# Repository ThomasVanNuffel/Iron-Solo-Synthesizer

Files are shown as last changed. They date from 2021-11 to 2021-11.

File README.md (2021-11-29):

# Main Directory
This repository is about the two phases of the project.

First phase: Practise Enterprise 1

    - XC888-DIL (microcontroller)
    - Input matrix with keys from keyboard
    - Led matrix
    - Serial interface with signal generators (with chip selector)

Second phase: Practise Enterprise 2

    - STM32F7508-DK (microcontroller)
    - Better serial interface with more signal generators
    - Communication with XC888 (to have all features of previous year)
    - MIDI communication
    - Hardware audio effects:
        - Envelopes
        - Low pass filter
        - High pas filter

    - Line input with small mixing stage

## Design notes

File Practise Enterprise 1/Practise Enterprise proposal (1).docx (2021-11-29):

# Practise Enterprise proposal

Thomas Van Nuffel

# Description

I want to make a synthesizer based on the XC888 which is compatible with MIDI. The synthesizer is a standalone, which only needs power to work. I will make an output stage with different kinds of jacks to connect to speakers etc. Also, a headphone connection will be applied.

## MIDI interface

This is not part of my project. I just want to make a synthesizer compatible with MIDI. But I do not make a full MIDI interface. Because of the simple reason, you have guys who build keyboards and guys who make MIDI interfaces. I make a keyboard compatible with MIDI, but I do not reinvent the MIDI. It exists and I use it. In my block diagram I added the MIDI interface but that is just because my keyboard works with MIDI I/O.

# Features

### General

I make a complete synthesizer. So, you can play a synthesizer. But my purpose is to make it simple for the user. So, with different modes the user can personalize for his own purpose.

The general features are:

- Synthesizer that is compatible with MIDI (to connect to pc or other devices)
- Making sound due incoming MIDI signals
- Output to speakers/ headphones
- Input going through an amplifier to the output.
- Leds are indicating which notes are on at the time.

### Modes

- Synth mode
  - All functions will work
  - MIDI still can be applied.
- MIDI mode
  - Every hardware for sound will be disabled (less power consumption)
- Adapter
  - In Synth mode: a power supply needs to be applied.
  - In MIDI mode: power supply or power from USB to PC

### Synth features

- Three basic output waveforms
  - Sinewave
  - Square wave
  - Triangle wave
- Effects
  - Envelope
    - This is a voltage controlled system with an attack and release
  - Low pass filter
  - High pass filter
- Output stage
  - Master
    - XLR
    - RCA
    - Jack
  - Headphone
- Mode to decide in which DDS the next sound will be generated.
  - One after the other, left to right, after that begin left.
  - Search for the first one which is not playing right now.

# Hardware I/O

## Input

- Maximal 96 keys

Sum is at absolute maximum 128

- Maximal 32 knobs
- Sliders (10)
- AUX in

## Output

- Audio master output (speakers)
  - RCA
  - XLR
  - Jack
- Headphone output
  - Jack
- Leds indicating which notes are pressed at the moment (midi or knobs)

## Other

- MIDI interface
- Power supply
  - Wall outlet
  - USB

# How it’s gonna work

You plug it in the wall outlet. The controller has an on/Off knob. Turn it on. Choose MIDI mode or Synth mode. A synthesizer speaks for itself how to use it. It has built-in speakers, so you do not need external speakers. Connect to a MIDI interface to use as a MIDI keyboard. You can play notes, you can use sliders. Dipswitches are indicating which region of the keyboard is enabled for controlling by knobs, the other parts are MIDI only. This will result in an interactive learn function.

# Extra features (if there is time left)

I am thinking of making some extra features with:

- Add more input
- Add more effects
- Optimize my synths compatibility with any DAW on my computer by MIDI. For example, that slider is assigned to this effect in any software.
- Give the leds on top of the keys another color (daresay one color for all the leds)
- Improving the “Learn to play” function.

# Photos

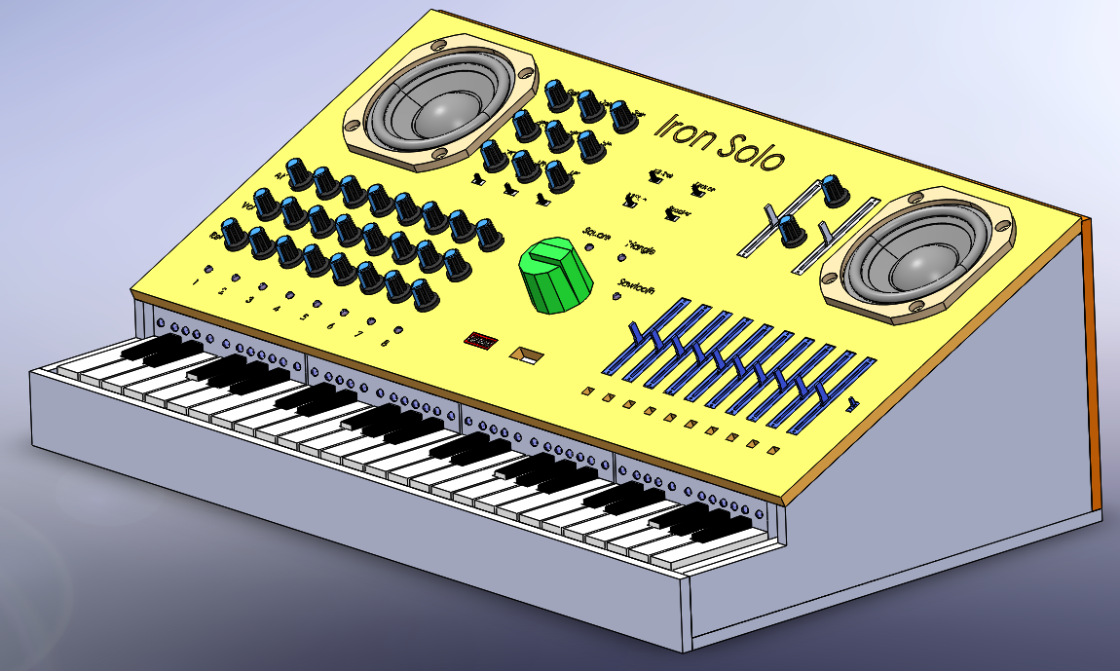
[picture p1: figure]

Master section

LPF and HPF

8 DDS modules with envelope and volume

MIDI sliders

Waveform selector

49 leds

Region selector

49 keys

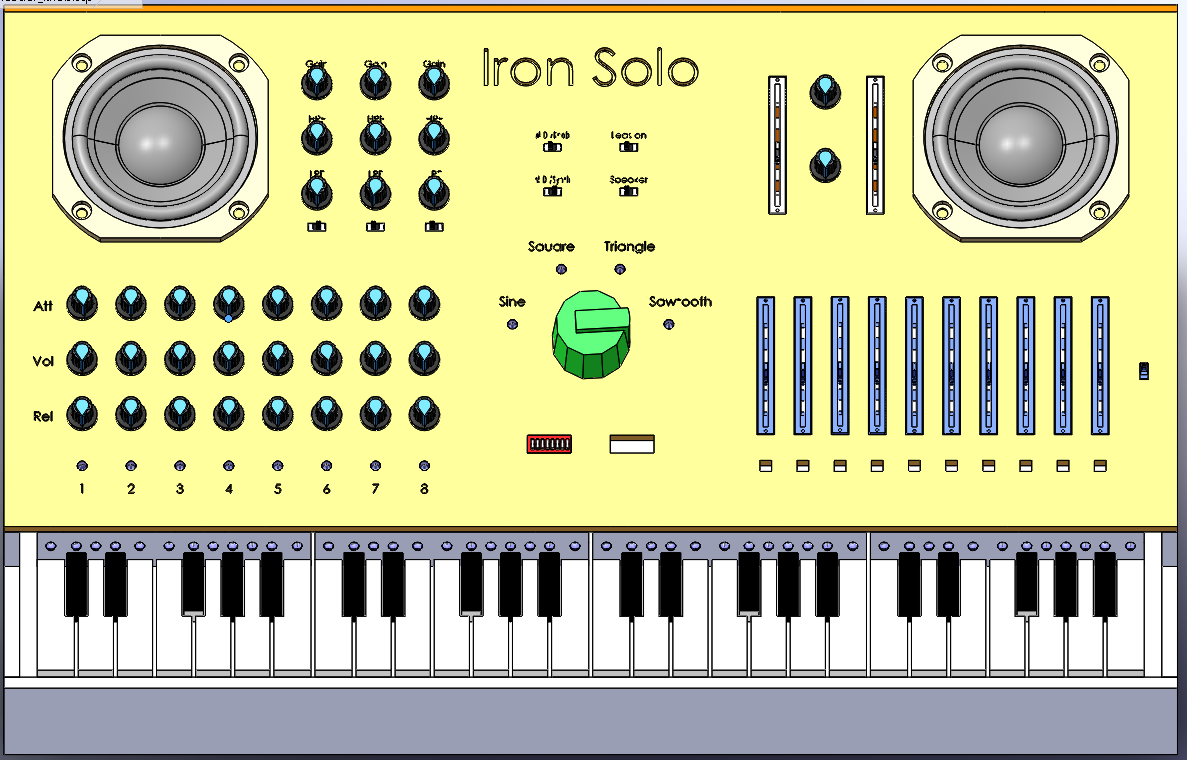
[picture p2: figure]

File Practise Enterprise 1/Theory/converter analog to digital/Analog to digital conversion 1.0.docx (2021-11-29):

# Analog to digital conversion

# Intro:

An analog signal is a signal that is continuously in time and in amplitude. The resolution is by definition infinitely. When an analog signal is made digital does this mean that we need to discretize the signal. A discrete digital signal is the counterpart of a continuous signal. To make it digital we need to take a moment and save it. Then take the next moment and save it again. This happens at a certain frequency. That frequency is called the sampling frequentie. Every moment there will be a sample of the sound, and many sounds after each other will result in a more or less smooth signal. The higher this sample frequency, the higher the resolution of the sound.

# Working

The analog signal is coming into the AD-converter and will be edited by a low pass filter. This is done for preventing aliasing. This occurs when the sample frequentie isn’t at least two times higher then the highest frequentie. If the sound frequency is too high in relation to the sample frequency, you get audio with horrible sound in the high frequencies. So our sample frequency must be high enough to pass high frequency sound (20kHz). So we need to sample at least 40.000Hz, or the standard sampling frequency of 44.100Hz. After this low pass filter the ADC takes samples at the sample frequency. This means that we are going to look at the exact amplitude of the sound wave. Well known systems are the voice telephony with a sample rate of 8kHz. So the maximal frequency we can sample is 4kHz (due the aliasing low pass filter). Every sample, every amplitude is a number that contains bits. The amount of bits determines how exactly the signal is measured. And that’s logical. Because if you have to divide a signal over 8 bits. Or you have to divide that same signal over 32 bits. The precision of the 32 bits is four times better then the 8 bits. When the analog signal is filtered and quantized. The analog signal has become digital.

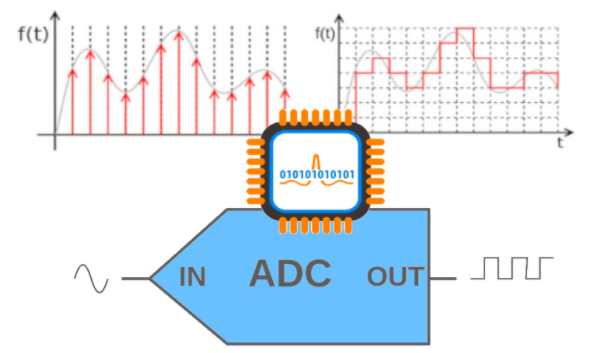
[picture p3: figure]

## Summary

- The analog input is quantized in digital amplitudes.
- The more refined the quantization. The higher the amount of bits needed.
- The bigger the amount of bits per amplitude the exacter the signal.
- The bigger the sample frequency, the bigger is the highest frequency without aliasing

## The implementation

Sampling uses a “sample-and-hold circuit”. At fixed time a sample is made from the analog signal. You can see it as a switch that turns on and off at fixed times. And a capacitor is used for holding the “memory” of that one amplitude.

That amplitude is compared to fixed levels. Here is a rounding error. This is the quantisation noise. The network to do this is a series circuit of four resistors where a reference voltage is applied to. After the first resistor you have 25% of the voltage. After the second one you have 50%, after the third 75% and after the fourth 100% of the voltage. These levels are together with the sample connected to a differential amplifier.

- If the sample amplitude is bigger then 25%, the output of the first differential amplifier changes polarity
- If the sample amplitude is bigger then 50%, the output of the second differential amplifier changes polarity
- If the sample amplitude is bigger then 75%, the output of the third differential amplifier changes polarity
- If the sample amplitude is bigger then 100%, the output of the fourth differential amplifier changes polarity

And last but not least you have a logic circuit which is granting binary numbers to the signal.

- Level 1 is 00(2)
- Level 2 is 01(2)
- Level 3 is 10(2)
- Level 4 is 11(2)

## Improve the quality

- Increase the amount of samples per second
- Increase the amount of bits per sample
- Faster sample-and-hold circuit
- More extensive networks
- Every bit extra is a doubling of the amount of resistors needed
- The tolerance on the resistors must be as low as possible

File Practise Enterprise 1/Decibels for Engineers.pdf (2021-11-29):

Decibels for engineers.

While dB is a very handy way of expressing large numbers, like we often have to deal with in amplifier circuits, unfortunately a lot of engineers fail the ability to juggle with them. So apart from the “official” mathematical way of dealing with dB’s, we will now learn a handy way how to use them by only remembering 3 numbers.

Decibel is a number that describes how the ratio is between two voltages or two powers

Voltage dB = 20 * LOG (A1 / A2)

Power dB = 10 * LOG (P1 / P2)

As we do not always have a scientific calculator at hand there is is truck that helps you handle these memorizing only 3 numbers:

POWER deciBels (small d capital B)

times two = + 3 dB

divided by two = - 3 dB

times four = + 6 dB

divided by four = - 6 dB

times ten = + 10 dB

divided by ten = - 10 dB

other values can be derived from this, like FIVE = TEN divided by TWO = +10 dB – 3 dB = 5 dB

times hundred = TEN times TEN = +10 dB + 10 dB = 20 dB

VOLTAGE deciBels

times two = + 6 dB

divided by two = - 6 dB

times four = + 12 dB

divided by four = - 12 dB

times ten = + 20 dB

divided by ten = - 20 dB

## An overview:

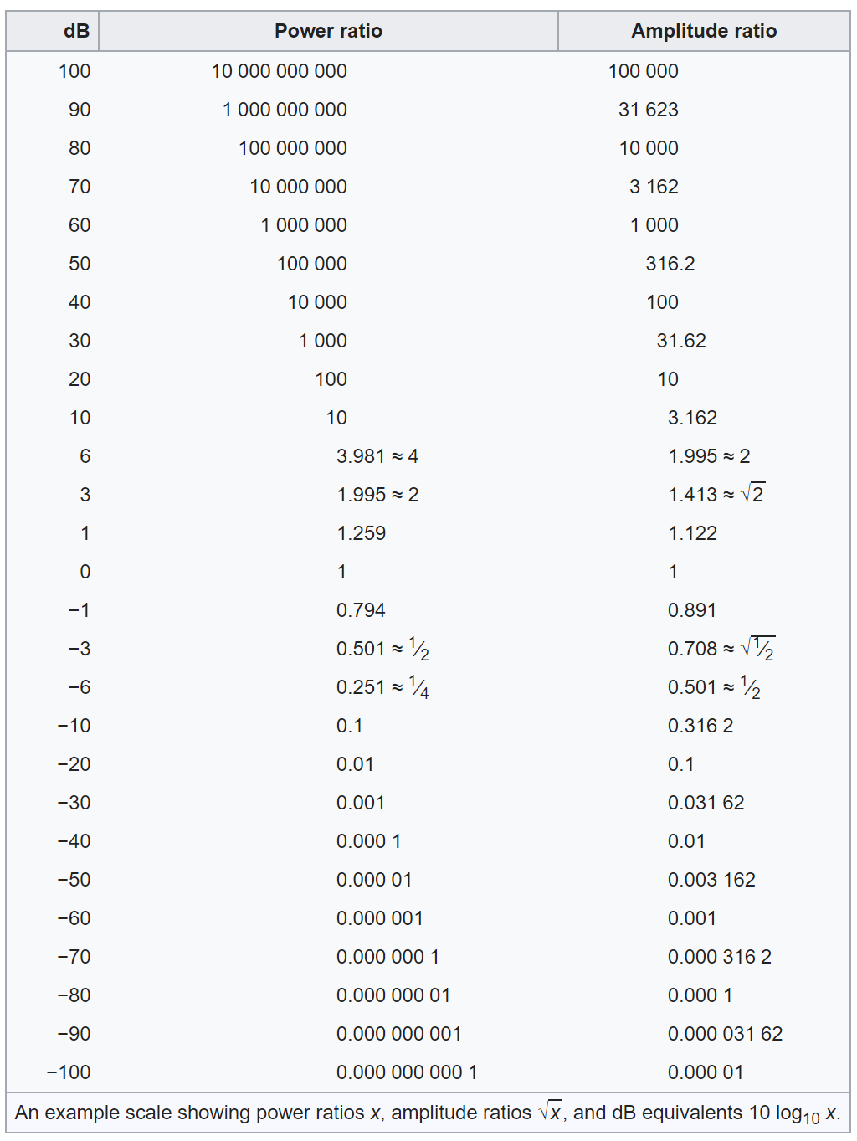
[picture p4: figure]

(source https://en.wikipedia.org/wiki/Decibel )

## Exercices:

An antenna is driven by a transmitter power of 1000 Watts. How much is this in dBm ? (dBm is the power output compared to 1 mW)

A microphone amplifier has a voltage gain of 100, How many dB’s gain has it ?

The noise floor of a PA system is 1.000.000 below the nominal output power. How much is the signal to noise ratio ?

A system consists of 3 cascaded amplifiers, the first one having 1000 times voltage amplification, the second 500 and the last stage 40. How much is the total gain in dB.

A 100 Watts transmitter is feeding a 6 dB gain antenna using a cable that has 3 dB loss. How much is the effectively radiated power in dBm ?

A satellite van has a dish antenna with 60 dB gain and is driven by a travelling wave tube amplifier that has a maximum output power of 500W via a waveguide that has 3 dB loss. How much is the effectively radiated power in dBW ?

The signal at the output of a low noise microphone amplifier is 1 Vpp. The signal to noise ratio is 80 dB. How much is the noise level at the output and how much is the microphone signal at the input when the amplifier has a 1000 times voltage gain ?

The maximum input power of an amplifier is 0 dBm while the uncompressed gain is 40 dB. How much Watts will the amplifier deliver to the load ?

A cabling system at a cellphone tower consists of a patch cable of 0,3 dB loss, followed by a feed line that has 1,5 dB loss, an antenna splitter that has 3 dB loss and an antenna feed patch line that adds another 0,2 dB of loss.. When the transmitter delivers a power output of 20 dBW, how much power will my Bird Wattmeter indicate at the antenna terminal (in Watts) ?

An active speaker clips at 10V output level over a 4 ohms speaker resistance at an input voltage of 250 mV. How much is the system gain ?

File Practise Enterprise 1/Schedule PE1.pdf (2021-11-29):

Project Start: 12/10/2020 | Week:1
| | | | 12 | 13
Task | Start | Progress | End | ma | di
Urenregistratie!A1 | Total: | 14 okt 20 | 74% | 30 mei 21
Preparations | 18 okt 20 | 100% | 20 okt 20 | X
https://www.youtube.com/watch?v=un8j6QqpYa0&t=646s Knowing how this works | 18 okt 20 | 100% | 19 okt 20 | X
Getting a Gantt Chart | 19 okt 20 | 100% | 20 okt 20 | X
..\Theory Theory | 18 okt 20 | 100% | 22 jan 21 | X
..\Theory\XC888 Datasheet XC888 | 27 okt 20 | 100% | 15 dec 20 | X
Sensor Research | 19 okt 20 | 100% | 01 dec 20 | X
Scan matrix keys + leds | 14 nov 20 | 100% | 18 nov 20 | X
MIDI | 18 okt 20 | 100% | 29 dec 20 | X
MIDI coding | 28 dec 20 | 100% | 29 dec 20 | X
Analog voltages due PWM | 28 dec 20 | 100% | 29 dec 20 | X
AD9833 | 16 jan 21 | 100% | 22 jan 21 | X
Decibels | 19 dec 20 | 100% | 11 jan 21 | X
Documentation | 14 okt 20 | 73% | 11 apr 21
..\Theory\MIDI MIDI documentation | 14 okt 20 | 100% | 03 nov 20 | X
Scan Matrices | 02 apr 21 | 70% | 11 apr 21
Sound | 17 nov 20 | 100% | 18 nov 20 | X
Hearing | 18 nov 20 | 100% | 18 nov 20 | X
Effects | 01 apr 21 | 70% | 11 apr 21
Envelope | 23 nov 20 | 100% | 12 jan 21 | X
Attenuator | 02 jan 21 | 100% | 07 jan 21 | X
Programming | 14 mrt 21 | 20%
3D design keyboard | | 0%
Schematics | 16 nov 20 | 85% | 11 apr 21
Scan Matrix keys | 16 nov 20 | 100% | 16 nov 20 | X
Master section | 12 dec 20 | 100% | 27 dec 20 | X
Attenuator | 03 jan 21 | 100% | 07 jan 21 | X
Envelope | 03 jan 21 | 100% | 11 jan 21 | X
Envelope2.0 | 28 jan 21 | 100% | 01 feb 21 | X

LPF | 09 jan 21 | 100% | 31 jan 21 | X
HPF | 09 jan 21 | 100% | 31 jan 21 | X
Scan matrix keys | 30 jan 21 | 100% | 30 jan 21 | X
Scan Matrix Leds | 14 mrt 21 | 100% | 11 apr 21 | X
Routings of XC888 | 12 jan 21 | 100% | 25 feb 21
Master section 2.0 | | 0%
Line input amplifier | | 0%
Block diagram | 21 jan 21 | 100% | 10 feb 21 | X
3D design keyboard | 07 feb 21 | 92% | 15 feb 21
Main plate | 07 feb 21 | 95%
Connections input/output audio | 08 feb 21 | 80% | 13 feb 21
Keys implemented | 09 feb 21 | 100% | 15 feb 21 | X
Components | 25 jan 21 | 100% | 19 mrt 21 | X
Speakers | 18 feb 21 | 100% | 08 mrt 21 | X
AD9833 | 25 jan 21 | 100% | 19 mrt 21 | X
Connectors | 25 jan 21 | 100% | 08 mrt 21 | X
XLR | 18 feb 21 | 100% | 08 mrt 21 | X
Jacks | 18 feb 21 | 100% | 08 mrt 21 | X
MIDI | 18 feb 21 | 100% | 08 mrt 21 | X
Log potmeters | 18 feb 21 | 100% | 08 mrt 21 | X
Capacitors | 04 mrt 21 | 100% | 04 mrt 21 | X
Resistors | 04 mrt 21 | 100% | 04 mrt 21 | X
PCB's | 01 feb 21 | 100% | 15 feb 21
Coding | 21 jan 21 | 61% | 25 apr 21
Initialisation | | 97%
SPI interface | 13 mrt 21 | 100% | 15 mrt 21 | X
UART interface | 21 jan 21 | 100% | 24 jan 21 | X
Reset values | | 90%
UART interface | 26 jan 21 | 36% | 11 apr 21
Transmitting | 26 jan 21 | 73% | 26 jan 21
Note on | 26 jan 21 | 100% | 26 jan 21 | X
Note off | 26 jan 21 | 100% | 26 jan 21 | X
Control change | 15 mrt 21 | 90% | 15 mrt 21
Program change | 05 apr 21 | 0% | 11 apr 21

Receiving | 05 apr 21 | 0% | 11 apr 21
Note on | 05 apr 21 | 0% | 11 apr 21
Note off | 05 apr 21 | 0% | 11 apr 21
Communication AD9833 | | 70%
SPI interface | 14 mrt 21 | 90% | 11 apr 21
Coding frequencies | 16 mrt 21 | 50% | 25 apr 21
Scan matrices | | 95%
Reading knobs | 24 jan 21 | 90% | 11 apr 21
Writing leds | 24 jan 21 | 100% | 25 jan 21 | X
Register assigning | 05 feb 21 | 70%
All notes done | | 0%
Assembly | 18 mrt 21 | 26% | 18 apr 21
Soldering Envelopes | 27 mrt 21 | 33% | 27 mrt 21
Soldering Effect | 28 mrt 21 | 70% | 11 apr 21 | X
Soldering protoboards | 05 apr 21 | 0% | 11 apr 21
Soldering Attenuators | 18 mrt 21 | 25% | 11 apr 21
Assembly wooden case | 12 apr 21 | 0% | 18 apr 21
Implement keys | 12 apr 21 | 0% | 14 apr 21
Insert every potentiometer | 14 apr 21 | 0% | 18 apr 21
Website engineering | 23 feb 21 | 53% | 24 feb 21
Info.html | 23 feb 21 | 80% | 24 feb 21
ISS.html | 23 feb 21 | 30%
Laboratorium.html | 23 feb 21 | 50%
ISS.CSS | 23 feb 21 | 50%
Extra | 28 nov 20 | 70% | 00 jan 00
LED's on output | 28 nov 20 | 70%

Practise (https://docs.google.com/document/d/1_m2AN_rFxQbSherB3lgHLhHfU028Jz2VM6xTpPx7AJo/edit) Enterprise book Practise Enterprise 1 book

14 | 15 | 16 | 17 | 18 | 19 | 20 | 21 | 22 | 23 | 24 | 25 | 26 | 27 | 28 | 29 | 30 | 31 | 1 | 2 | 3 | 4 | 5 | 6
wo do | vr | za | zo ma | di | wo do | vr | za | zo ma | di | wo do | vr | za | zo ma | di | wo do | vr
12/10 - 18/10 | 19/10 - 25/10 | 26/10 - 1/11 | 2/11 - 8/11

7 | 8 | 9 | 10 | 11 | 12 | 13 | 14 | 15 | 16 | 17 | 18 | 19 | 20 | 21 | 22 | 23 | 24 | 25 | 26 | 27 | 28 | 29 | 30
za | zo ma | di | wo do | vr | za | zo ma | di | wo do | vr | za | zo ma | di | wo do | vr | za | zo ma
8/11 | 9/11 - 15/11 | 16/11 - 22/11 | 23/11 - 29/11

1 | 2 | 3 | 4 | 5 | 6 | 7 | 8 | 9 | 10 | 11 | 12 | 13 | 14 | 15 | 16 | 17 | 18 | 19 | 20 | 21 22 | 23 | 24
di | wo do | vr | za | zo ma | di | wo do | vr | za | zo ma | di | wo do | vr | za | zo ma | di | wo do
30/11 - 6/12 | 7/12 - 13/12 | 14/12 - 20/12 | 21/12 -

25 | 26 | 27 | 28 | 29 | 30 | 31 | 1 | 2 | 3 | 4 | 5 | 6 | 7 | 8 | 9 | 10 | 11 | 12 | 13 | 14 | 15 | 16 | 17
vr | za | zo ma | di | wo do | vr | za | zo ma | di | wo do | vr | za | zo ma | di | wo do | vr | za | zo

### Practise enterprise 1 By Thomas Van Nuffel

27/12 | 28/12 - 3/01 | 4/01 - 10/01 | 11/01 - 17/01

18 | 19 | 20 | 21 | 22 | 23 | 24 | 25 | 26 | 27 | 28 | 29 | 30 | 31 | 1 | 2 | 3 | 4 | 5 | 6 | 7 | 8 | 9 | 10
ma | di | wo do | vr | za | zo ma | di | wo do | vr | za | zo ma | di | wo do | vr | za | zo ma | di | wo

### Practise enterprise 1 By Thomas Van Nuffel

18/01 - 24/01 | 25/01 - 31/01 | 1/02 - 7/02 | 8/02 -

11 | 12 | 13 | 14 | 15 | 16 | 17 | 18 | 19 | 20 | 21 | 22 | 23 | 24 | 25 | 26 | 27 | 28 | 1 | 2 | 3 | 4 | 5 | 6
do | vr | za | zo ma | di | wo do | vr | za | zo ma | di | wo do | vr | za | zo ma | di | wo do | vr | za
8/02 - 14/02 | 15/02 - 21/02 | 22/02 - 28/02 | 1/03 - 7/03

7 | 8 | 9 | 10 | 11 | 12 | 13 | 14 | 15 | 16 | 17 | 18 | 19 | 20 | 21 | 22 | 23 | 24 | 25 | 26 | 27 | 28 | 29 | 30
zo ma | di | wo do | vr | za | zo ma | di | wo do | vr | za | zo ma | di | wo do | vr | za | zo ma | di
8/03 - 14/03 | 15/03 - 21/03 | 22/03 - 28/03

31 | 1 | 2 | 3 | 4 | 5 | 6 | 7 | 8 | 9 | 10 | 11 | 12 | 13 | 14 | 15 | 16 | 17 | 18 | 19 | 20 | 21 | 22 | 23
wo do | vr | za | zo ma | di | wo do | vr | za | zo ma | di | wo do | vr | za | zo ma | di | wo do | vr
29/03 - 4/04 | 5/04 - 11/04 | 12/04 - 18/04 | 19/04 - 25/04

24 | 25 | 26 | 27 | 28 | 29 | 30 | 1 | 2 | 3 | 4 | 5 | 6 | 7 | 8 | 9
za | zo ma | di | wo do | vr | za | zo ma | di | wo do | vr | za | zo
25/04 | 26/04 - 2/05 | 3/05 - 9/05
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

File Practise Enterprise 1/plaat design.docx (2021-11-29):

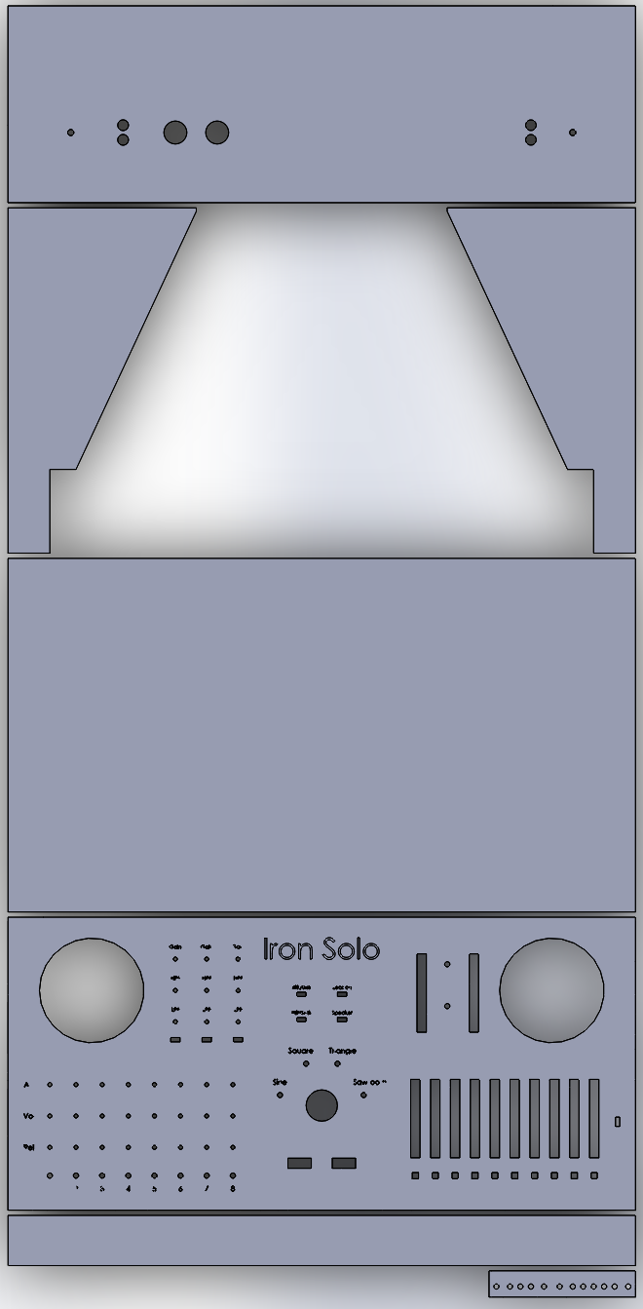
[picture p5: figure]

Horizontaal verticaal

600 188

600 338

600 280

600 48

600 25

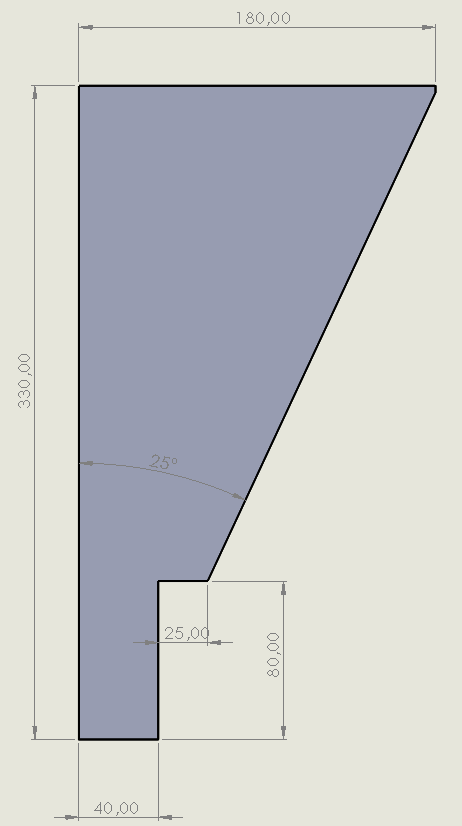
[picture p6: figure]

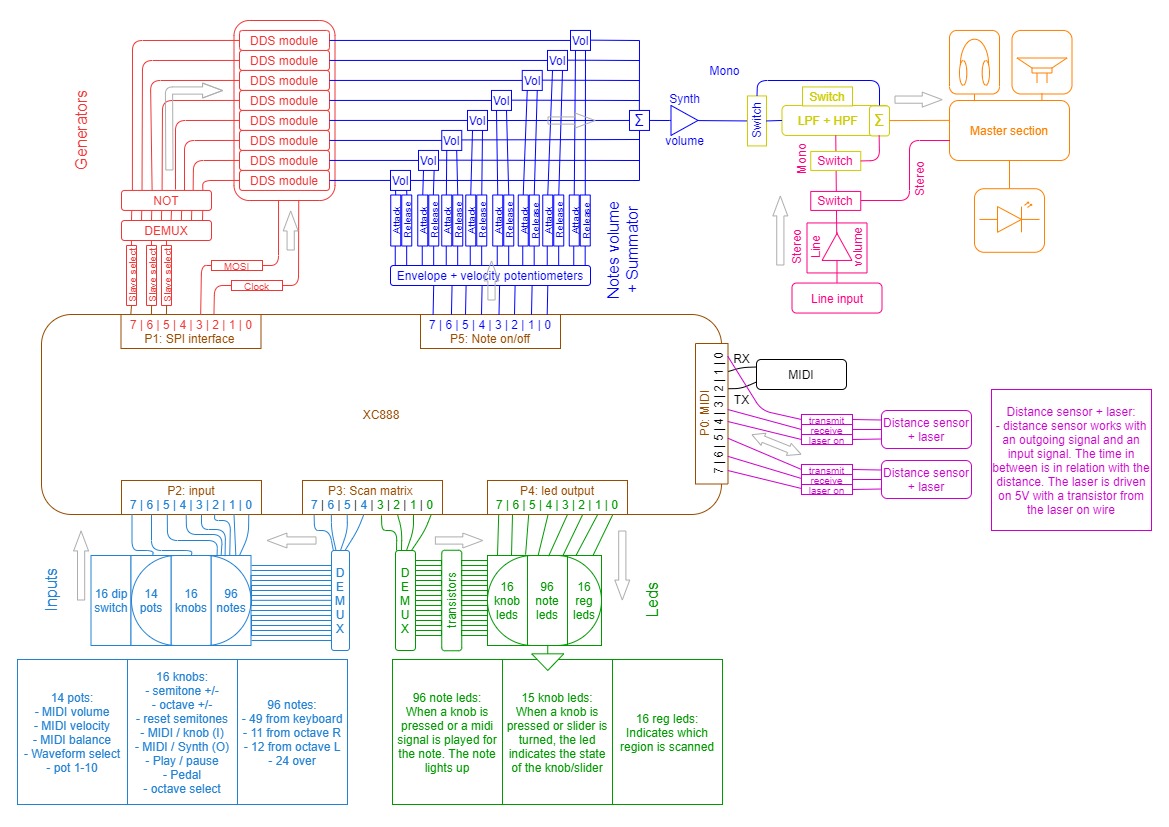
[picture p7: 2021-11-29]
Practise Enterprise 1/Design/Full hardware schematic.jpg

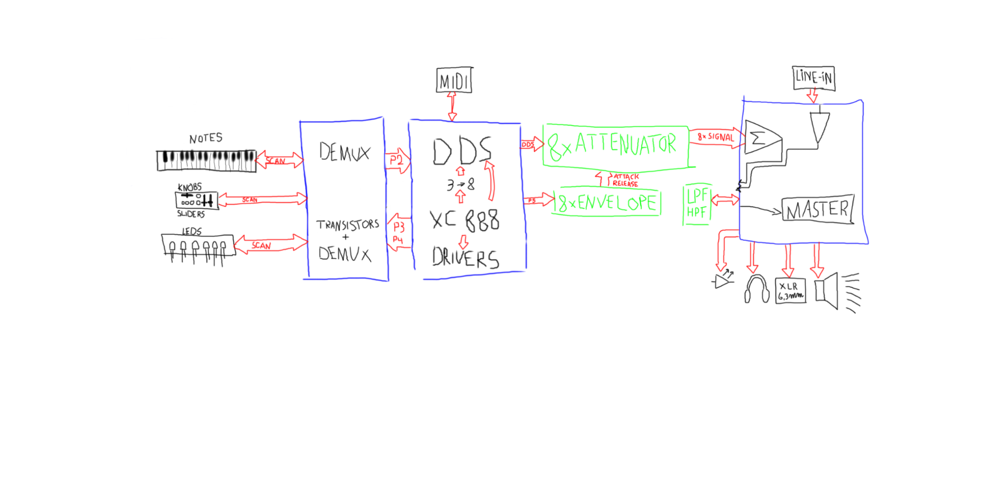
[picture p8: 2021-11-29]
Practise Enterprise 1/Drawings/Hardware block schematic.tif

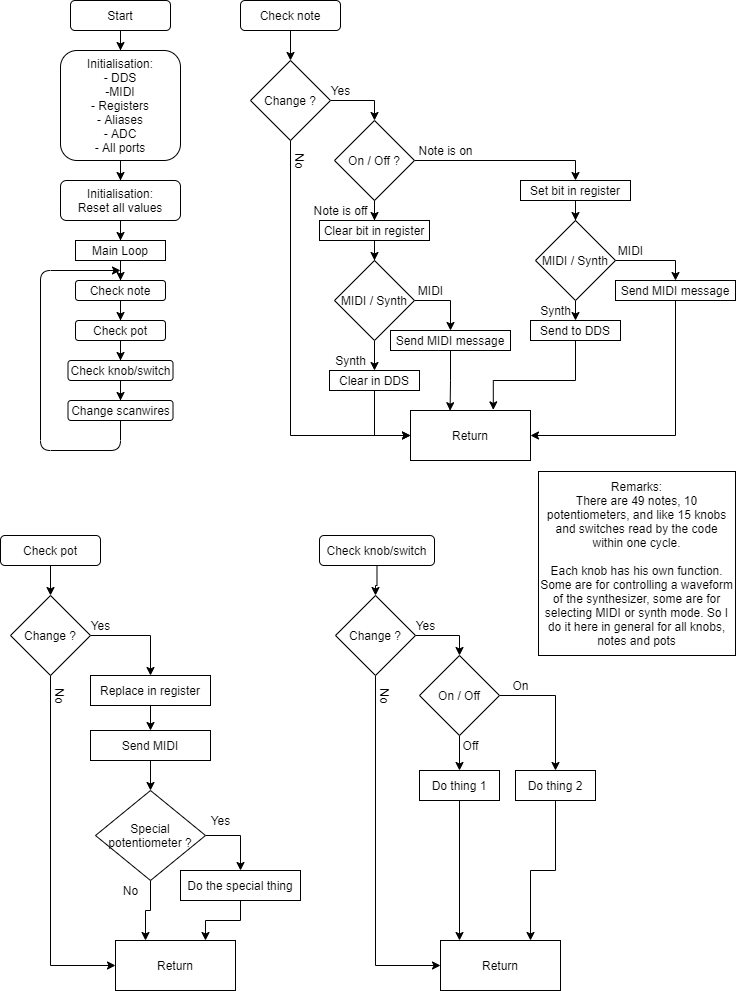
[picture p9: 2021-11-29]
Practise Enterprise 1/Schematic/Definitief code.png

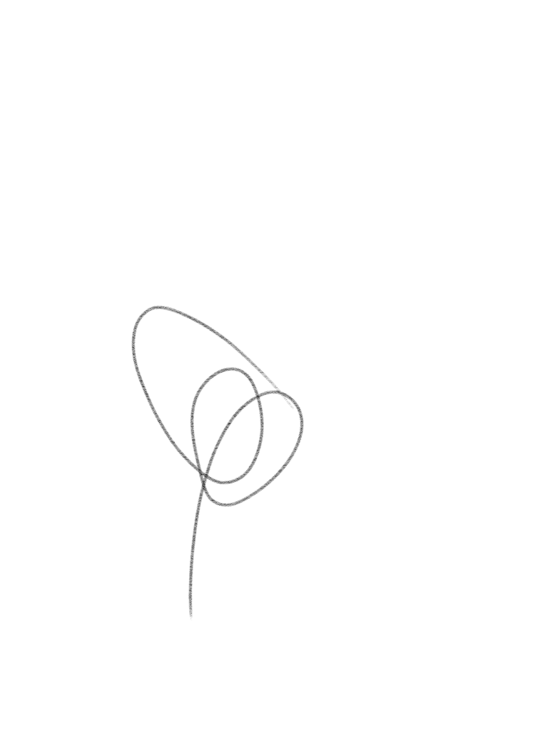
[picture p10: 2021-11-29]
Practise Enterprise 1/Drawings/sketch1616422383423.png

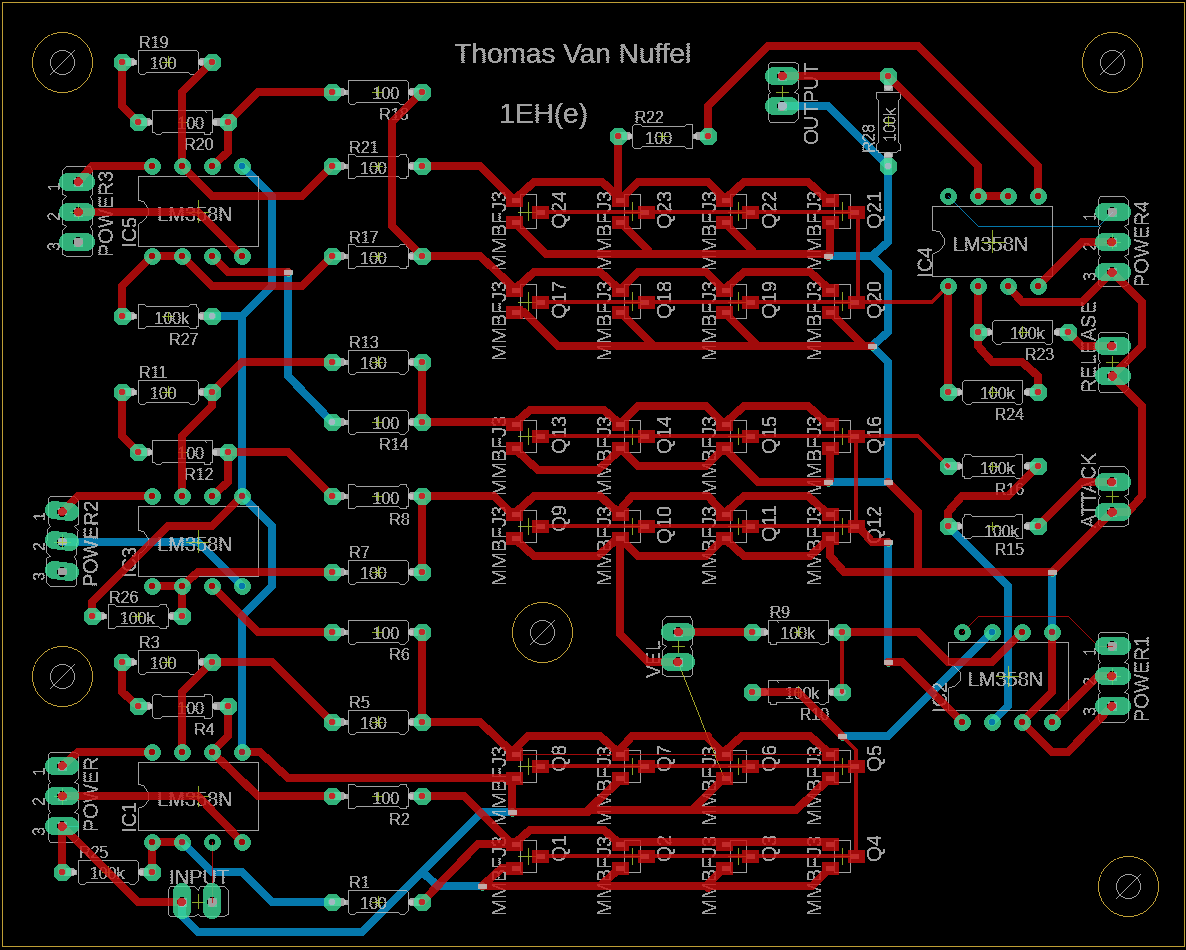
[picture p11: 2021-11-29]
Practise Enterprise 1/PCB/Nieuwe map/Attenuator board.png

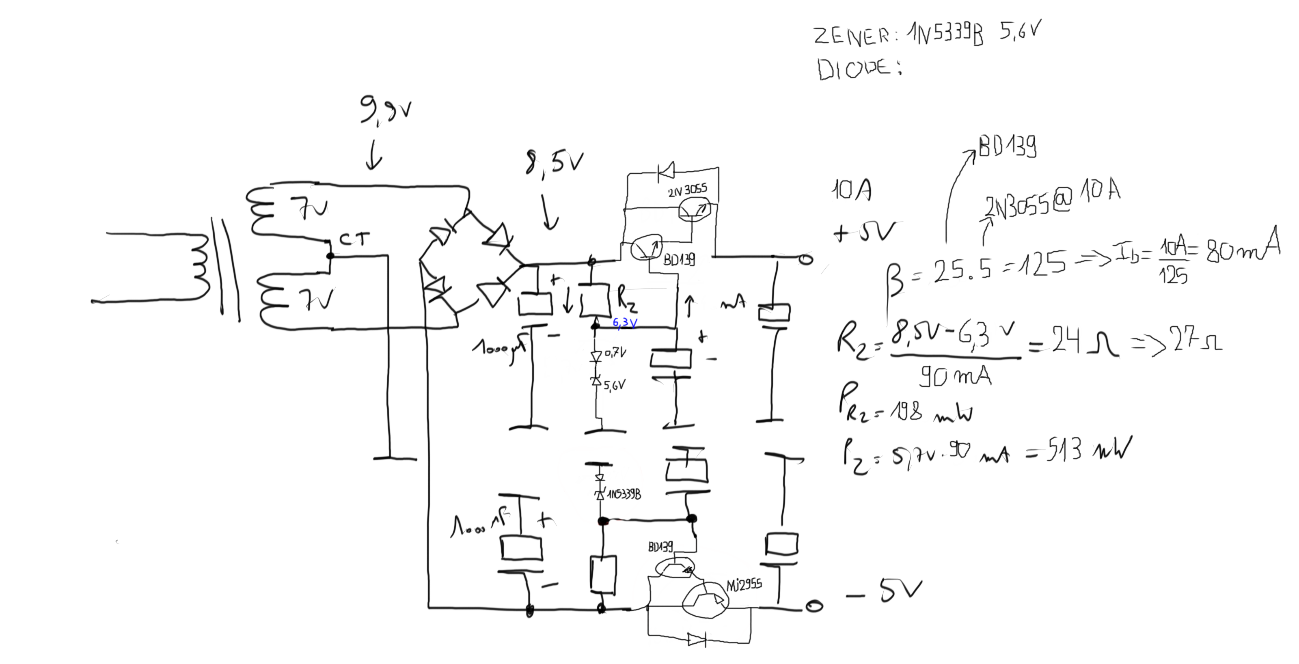
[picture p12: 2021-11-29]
Practise Enterprise 1/Drawings/symmetrical power supply example.png

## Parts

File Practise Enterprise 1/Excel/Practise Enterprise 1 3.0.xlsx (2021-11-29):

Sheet: Gantt Chart
 |  |  |  |  |  | Practise enterprise 1 By Thomas Van Nuffel
 | 2020-10-12 | Week:1 |  |  |  | 2020-10-12 |  |  |  | 2020-10-18 |  |  | 2020-10-19 |  |  |  | 2020-10-25 |  |  | 2020-10-26 |  |  |  | 2020-11-01 |  |  | 2020-11-02 |  |  |  | 2020-11-08 |  |  | 2020-11-09 |  |  |  | 2020-11-15 |  |  | 2020-11-16 |  |  |  | 2020-11-22 |  |  | 2020-11-23 |  |  |  | 2020-11-29 |  |  | 2020-11-30 |  |  |  | 2020-12-06
 |  |  |  |  |  | 2020-10-12 | 2020-10-13 | 2020-10-14 | 2020-10-15 | 2020-10-16 | 2020-10-17 | 2020-10-18 | 2020-10-19 | 2020-10-20 | 2020-10-21 | 2020-10-22 | 2020-10-23 | 2020-10-24 | 2020-10-25 | 2020-10-26 | 2020-10-27 | 2020-10-28 | 2020-10-29 | 2020-10-30 | 2020-10-31 | 2020-11-01 | 2020-11-02 | 2020-11-03 | 2020-11-04 | 2020-11-05 | 2020-11-06 | 2020-11-07 | 2020-11-08 | 2020-11-09 | 2020-11-10 | 2020-11-11 | 2020-11-12 | 2020-11-13 | 2020-11-14 | 2020-11-15 | 2020-11-16 | 2020-11-17 | 2020-11-18 | 2020-11-19 | 2020-11-20 | 2020-11-21 | 2020-11-22 | 2020-11-23 | 2020-11-24 | 2020-11-25 | 2020-11-26 | 2020-11-27 | 2020-11-28 | 2020-11-29 | 2020-11-30 | 2020-12-01 | 2020-12-02 | 2020-12-03 | 2020-12-04
 | Task | Start | Progress | End |  | ma | di | wo | do | vr | za | zo | ma | di | wo | do | vr | za | zo | ma | di | wo | do | vr | za | zo | ma | di | wo | do | vr | za | zo | ma | di | wo | do | vr | za | zo | ma | di | wo | do | vr | za | zo | ma | di | wo | do | vr | za | zo | ma | di | wo | do | vr
Urenregistratie!A1 | Total: | 2020-10-14 | 25.31505532% | 2021-05-30
 | Preparations | 2020-10-18 | 100% | 2020-10-20 | X
https://www.youtube.com/watch?v=un8j6QqpYa0&t=646s | Knowing how this works | 2020-10-18 | 100% | 2020-10-19 | X
 | Getting a Gantt Chart | 2020-10-19 | 100% | 2020-10-20 | X
..\Theory | Theory | 2020-10-19 | 31.58730159% | 2020-12-01
..\Theory\XC888 | Datasheet XC888 | 2020-10-27 | 14.28571429% | 2020-11-22
 | Sensor Research | 2020-10-19 | 70% | 2020-12-01
 | Scan matrix keys + leds | 2020-11-14 | 100% | 2020-11-18 | X
 | Digital and analog reading of a pin |  | 0%
 | Digital to analog conversion | 2020-11-09 | 0%
 | Store data on external drives |  | 0%
 | Communication XC888s | 2020-11-11 | 100% | 2020-12-01 | X
 | PWM |  | 0%
 | MIDI |  | 0%
 | Documentation | 2020-10-14 | 53.63636364% | 2020-11-18
..\Theory\MIDI | MIDI documentation | 2020-10-14 | 100% | 2020-11-03 | X
..\Theory\converter analog to digital\Analog to digital conversion 1.0.docx | Analog to digital conversion | 2020-11-02 | 100% | 2020-11-02 | X
 | Digital to analog conversion | 2020-11-09 | 60%
 | Scan matrix keys | 2020-11-15 | 80%
 | Matrix for driving leds |  | 40%
 | Sound | 2020-11-17 | 100% | 2020-11-18 | X
 | Hearing | 2020-11-18 | 100% | 2020-11-18
 | Sensors |  | 0%
 | Storage management |  | 0%
 | Communication XC888s |  | 0%
 | Terminology | 2020-11-02 | 10%
 | Schematics | 2020-11-16 | 33.33333333% | 2020-11-16
 | The schematic of my project |  | 0%
 | Scan Matrix keys | 2020-11-16 | 100% | 2020-11-16 | X
 | Scan Matrix leds |  | 0%
 | Place of XC888(s) and input and output |  | 0%
 | To-do | 2020-11-15 | 33.33333333% | 2020-11-15
..\Theory\Scan Matrix | Figure out scan Matrix | 2020-11-15 | 100% | 2020-11-15 | X
 | Using the buzzer of the XC888 |  | 0%
 | Searching wavetables |  | 0%
 | Designs and buildings | 0 | 0% | 0
 | Design PCB |  | 0%
 | Housing distance and laser |  | 0%
 | Pedal |  | 0%
 | 3D printed things | 0 | 0% | 0
 | Housing distance and laser |  | 0%
 | Pedal |  | 0%
 | Extra | 2020-11-02 | 25% | 2020-11-22
..\Theory\converter analog to digital | Analog to digital conversion | 2020-11-02 | 100% | 2020-11-22 | X
 | Analog to digital converter |  | 0%
 | Input amplifier to output |  | 0%
 | LED's on output |  | 0%
Practise Enterprise book (https://docs.google.com/document/d/1_m2AN_rFxQbSherB3lgHLhHfU028Jz2VM6xTpPx7AJo/edit) | Practise Enterprise 1 book

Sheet: Registration
Practise Enterprise 1
Day | Date | Subject | What did you do ? | Time spend in minutes | Total hours | Subtotals
 | Daarvoor | MIDI theory Asking Permission | documentation Sending mails | 600 mins | 10.0u
Ma | 2020-10-19 | Documentation | Which messages have which parameters | 120 mins | 2.0u | Total:2.0u
Di | 2020-10-20 |  |  |  | 0.0u
Wo | 2020-10-21 |  |  |  | 0.0u
Do | 2020-10-22 |  |  |  | 0.0u
Vr | 2020-10-23 |  |  |  | 0.0u
Za | 2020-10-24 |  |  |  | 0.0u
Zo | 2020-10-25 |  |  |  | 0.0u
Ma | 2020-10-26 |  |  |  | 0.0u | Total:1.8u
Di | 2020-10-27 |  |  |  | 0.0u
Wo | 2020-10-28 | To do | Search for components online | 46 mins | 0.8u
Do | 2020-10-29 |  |  |  | 0.0u
Vr | 2020-10-30 | Excel | Gant chart aangevuld | 60 mins | 1.0u
Za | 2020-10-31 |  |  |  | 0.0u
Zo | 2020-11-01 |  |  |  | 0.0u
Ma | 2020-11-02 | Theory | Analog to digital conversion | 120 mins | 2.0u | Total:2.2u
Di | 2020-11-03 | Documentation | Documentation ready on drive | 15 mins | 0.2u
Wo | 2020-11-04 |  |  |  | 0.0u
Do | 2020-11-05 |  |  |  | 0.0u
Vr | 2020-11-06 |  |  |  | 0.0u
Za | 2020-11-07 |  |  |  | 0.0u
Zo | 2020-11-08 |  |  |  | 0.0u
Ma | 2020-11-09 |  |  |  | 0.0u | Total:4.5u
Di | 2020-11-10 |  |  | 30 mins | 0.5u
Wo | 2020-11-11 |  |  |  | 0.0u
Do | 2020-11-12 |  |  |  | 0.0u
Vr | 2020-11-13 |  |  |  | 0.0u
Za | 2020-11-14 |  |  |  | 0.0u
Zo | 2020-11-15 | Schematic + Theory | Matrices keys + leds on tinkercad XC888 datasheet | 240 mins | 4.0u
Ma | 2020-11-16 | Schematic | Scan matrix of keyboard on multisim | 60 mins | 1.0u | Total:4.0u
Di | 2020-11-17 | Excel + documentation | Gantt Chart What is sound ? | 180 mins | 3.0u
Wo | 2020-11-18 |  |  |  | 0.0u
Do | 2020-11-19 |  |  |  | 0.0u
Vr | 2020-11-20 |  |  |  | 0.0u
Za | 2020-11-21 |  |  |  | 0.0u
Zo | 2020-11-22 |  |  |  | 0.0u
Ma | 2020-11-23 |  |  |  | 0.0u | Total:0.0u
Di | 2020-11-24 |  |  |  | 0.0u
Wo | 2020-11-25 |  |  |  | 0.0u
Do | 2020-11-26 |  |  |  | 0.0u
Vr | 2020-11-27 |  |  |  | 0.0u
Za | 2020-11-28 |  |  |  | 0.0u
Zo | 2020-11-29 |  |  |  | 0.0u
Ma | 2020-11-30 |  |  |  | 0.0u | Total:0.0u
Di | 2020-12-01 |  |  |  | 0.0u
Wo | 2020-12-02 |  |  |  | 0.0u
Do | 2020-12-03 |  |  |  | 0.0u
Vr | 2020-12-04 |  |  |  | 0.0u
Za | 2020-12-05 |  |  |  | 0.0u
Zo | 2020-12-06 |  |  |  | 0.0u
Ma | 2020-12-07 |  |  |  | 0.0u | Total:0.0u
Di | 2020-12-08 |  |  |  | 0.0u
Wo | 2020-12-09 |  |  |  | 0.0u
Do | 2020-12-10 |  |  |  | 0.0u
Vr | 2020-12-11 |  |  |  | 0.0u
Za | 2020-12-12 |  |  |  | 0.0u
Zo | 2020-12-13 |  |  |  | 0.0u
Ma | 2020-12-14 |  |  |  | 0.0u | Total:0.0u
Di | 2020-12-15 |  |  |  | 0.0u
Wo | 2020-12-16 |  |  |  | 0.0u
Do | 2020-12-17 |  |  |  | 0.0u
Vr | 2020-12-18 |  |  |  | 0.0u
Za | 2020-12-19 |  |  |  | 0.0u
Zo | 2020-12-20 |  |  |  | 0.0u
Ma | 2020-12-21 |  |  |  | 0.0u | Total:0.0u
Di | 2020-12-22 |  |  |  | 0.0u
Wo | 2020-12-23 |  |  |  | 0.0u
Do | 2020-12-24 |  |  |  | 0.0u
Vr | 2020-12-25 |  |  |  | 0.0u
Za | 2020-12-26 |  |  |  | 0.0u
Zo | 2020-12-27 |  |  |  | 0.0u
Ma | 2020-12-28 |  |  |  | 0.0u | Total:0.0u
Di | 2020-12-29 |  |  |  | 0.0u
Wo | 2020-12-30 |  |  |  | 0.0u
Do | 2020-12-31 |  |  |  | 0.0u
Vr | 2021-01-01 |  |  |  | 0.0u
Za | 2021-01-02 |  |  |  | 0.0u
Zo | 2021-01-03 |  |  |  | 0.0u
Ma | 2021-01-04 |  |  |  | 0.0u | Total:0.0u
Di | 2021-01-05 |  |  |  | 0.0u
Wo | 2021-01-06 |  |  |  | 0.0u
Do | 2021-01-07 |  |  |  | 0.0u
Vr | 2021-01-08 |  |  |  | 0.0u
Za | 2021-01-09 |  |  |  | 0.0u
Zo | 2021-01-10 |  |  |  | 0.0u
Ma | 2021-01-11 |  |  |  | 0.0u | Total:0.0u
Di | 2021-01-12 |  |  |  | 0.0u
Wo | 2021-01-13 |  |  |  | 0.0u
Do | 2021-01-14 |  |  |  | 0.0u
Vr | 2021-01-15 |  |  |  | 0.0u
Za | 2021-01-16 |  |  |  | 0.0u
Zo | 2021-01-17 |  |  |  | 0.0u
Ma | 2021-01-18 |  |  |  | 0.0u | Total:0.0u
Di | 2021-01-19 |  |  |  | 0.0u
Wo | 2021-01-20 |  |  |  | 0.0u
Do | 2021-01-21 |  |  |  | 0.0u
Vr | 2021-01-22 |  |  |  | 0.0u
Za | 2021-01-23 |  |  |  | 0.0u
Zo | 2021-01-24 |  |  |  | 0.0u
Ma | 2021-01-25 |  |  |  | 0.0u | Total:0.0u
Di | 2021-01-26 |  |  |  | 0.0u
Wo | 2021-01-27 |  |  |  | 0.0u
Do | 2021-01-28 |  |  |  | 0.0u
Vr | 2021-01-29 |  |  |  | 0.0u
Za | 2021-01-30 |  |  |  | 0.0u
Zo | 2021-01-31 |  |  |  | 0.0u
Ma | 2021-02-01 |  |  |  | 0.0u | Total:0.0u
Di | 2021-02-02 |  |  |  | 0.0u
Wo | 2021-02-03 |  |  |  | 0.0u
Do | 2021-02-04 |  |  |  | 0.0u
Vr | 2021-02-05 |  |  |  | 0.0u
Za | 2021-02-06 |  |  |  | 0.0u
Zo | 2021-02-07 |  |  |  | 0.0u
Ma | 2021-02-08 |  |  |  | 0.0u | Total:0.0u
Di | 2021-02-09 |  |  |  | 0.0u
Wo | 2021-02-10 |  |  |  | 0.0u
Do | 2021-02-11 |  |  |  | 0.0u
Vr | 2021-02-12 |  |  |  | 0.0u
Za | 2021-02-13 |  |  |  | 0.0u
Zo | 2021-02-14 |  |  |  | 0.0u
Ma | 2021-02-15 |  |  |  | 0.0u | Total:0.0u
Di | 2021-02-16 |  |  |  | 0.0u
Wo | 2021-02-17 |  |  |  | 0.0u
Do | 2021-02-18 |  |  |  | 0.0u
Vr | 2021-02-19 |  |  |  | 0.0u
Za | 2021-02-20 |  |  |  | 0.0u
Zo | 2021-02-21 |  |  |  | 0.0u
Ma | 2021-02-22 |  |  |  | 0.0u | Total:0.0u
Di | 2021-02-23 |  |  |  | 0.0u
Wo | 2021-02-24 |  |  |  | 0.0u
Do | 2021-02-25 |  |  |  | 0.0u
Vr | 2021-02-26 |  |  |  | 0.0u
Za | 2021-02-27 |  |  |  | 0.0u
Zo | 2021-02-28 |  |  |  | 0.0u
Ma | 2021-03-01 |  |  |  | 0.0u | Total:0.0u
Di | 2021-03-02 |  |  |  | 0.0u
Wo | 2021-03-03 |  |  |  | 0.0u
Do | 2021-03-04 |  |  |  | 0.0u
Vr | 2021-03-05 |  |  |  | 0.0u
Za | 2021-03-06 |  |  |  | 0.0u
Zo | 2021-03-07 |  |  |  | 0.0u
Ma | 2021-03-08 |  |  |  | 0.0u | Total:0.0u
Di | 2021-03-09 |  |  |  | 0.0u
Wo | 2021-03-10 |  |  |  | 0.0u
Do | 2021-03-11 |  |  |  | 0.0u
Vr | 2021-03-12 |  |  |  | 0.0u
Za | 2021-03-13 |  |  |  | 0.0u
Zo | 2021-03-14 |  |  |  | 0.0u
Ma | 2021-03-15 |  |  |  | 0.0u | Total:0.0u
Di | 2021-03-16 |  |  |  | 0.0u
Wo | 2021-03-17 |  |  |  | 0.0u
Do | 2021-03-18 |  |  |  | 0.0u
Vr | 2021-03-19 |  |  |  | 0.0u
Za | 2021-03-20 |  |  |  | 0.0u
Zo | 2021-03-21 |  |  |  | 0.0u
Ma | 2021-03-22 |  |  |  | 0.0u | Total:0.0u
Di | 2021-03-23 |  |  |  | 0.0u
Wo | 2021-03-24 |  |  |  | 0.0u
Do | 2021-03-25 |  |  |  | 0.0u
Vr | 2021-03-26 |  |  |  | 0.0u
Za | 2021-03-27 |  |  |  | 0.0u
Zo | 2021-03-28 |  |  |  | 0.0u
Ma | 2021-03-29 |  |  |  | 0.0u | Total:0.0u
Di | 2021-03-30 |  |  |  | 0.0u
Wo | 2021-03-31 |  |  |  | 0.0u
Do | 2021-04-01 |  |  |  | 0.0u
Vr | 2021-04-02 |  |  |  | 0.0u
Za | 2021-04-03 |  |  |  | 0.0u
Zo | 2021-04-04 |  |  |  | 0.0u
Ma | 2021-04-05 |  |  |  | 0.0u | Total:0.0u
Di | 2021-04-06 |  |  |  | 0.0u
Wo | 2021-04-07 |  |  |  | 0.0u
Do | 2021-04-08 |  |  |  | 0.0u
Vr | 2021-04-09 |  |  |  | 0.0u
Za | 2021-04-10 |  |  |  | 0.0u
Zo | 2021-04-11 |  |  |  | 0.0u
Ma | 2021-04-12 |  |  |  | 0.0u | Total:0.0u
Di | 2021-04-13 |  |  |  | 0.0u
Wo | 2021-04-14 |  |  |  | 0.0u
Do | 2021-04-15 |  |  |  | 0.0u
Vr | 2021-04-16 |  |  |  | 0.0u
Za | 2021-04-17 |  |  |  | 0.0u
Zo | 2021-04-18 |  |  |  | 0.0u
Ma | 2021-04-19 |  |  |  | 0.0u | Total:0.0u
Di | 2021-04-20 |  |  |  | 0.0u
Wo | 2021-04-21 |  |  |  | 0.0u
Do | 2021-04-22 |  |  |  | 0.0u
Vr | 2021-04-23 |  |  |  | 0.0u
Za | 2021-04-24 |  |  |  | 0.0u
Zo | 2021-04-25 |  |  |  | 0.0u
Ma | 2021-04-26 |  |  |  | 0.0u | Total:0.0u
Di | 2021-04-27 |  |  |  | 0.0u
Wo | 2021-04-28 |  |  |  | 0.0u
Do | 2021-04-29 |  |  |  | 0.0u
Vr | 2021-04-30 |  |  |  | 0.0u
Za | 2021-05-01 |  |  |  | 0.0u
Zo | 2021-05-02 |  |  |  | 0.0u
Ma | 2021-05-03 |  |  |  | 0.0u | Total:0.0u
Di | 2021-05-04 |  |  |  | 0.0u
Wo | 2021-05-05 |  |  |  | 0.0u
Do | 2021-05-06 |  |  |  | 0.0u
Vr | 2021-05-07 |  |  |  | 0.0u
Za | 2021-05-08 |  |  |  | 0.0u
Zo | 2021-05-09 |  |  |  | 0.0u
Ma | 2021-05-10 |  |  |  | 0.0u | Total:0.0u
Di | 2021-05-11 |  |  |  | 0.0u
Wo | 2021-05-12 |  |  |  | 0.0u
Do | 2021-05-13 |  |  |  | 0.0u
Vr | 2021-05-14 |  |  |  | 0.0u
Za | 2021-05-15 |  |  |  | 0.0u
Zo | 2021-05-16 |  |  |  | 0.0u
Ma | 2021-05-17 |  |  |  | 0.0u | Total:0.0u
Di | 2021-05-18 |  |  |  | 0.0u
Wo | 2021-05-19 |  |  |  | 0.0u
Do | 2021-05-20 |  |  |  | 0.0u
Vr | 2021-05-21 |  |  |  | 0.0u
Za | 2021-05-22 |  |  |  | 0.0u
Zo | 2021-05-23 |  |  |  | 0.0u
Ma | 2021-05-24 |  |  |  | 0.0u | Total:0.0u
Di | 2021-05-25 |  |  |  | 0.0u
Wo | 2021-05-26 |  |  |  | 0.0u
Do | 2021-05-27 |  |  |  | 0.0u
Vr | 2021-05-28 |  |  |  | 0.0u
Za | 2021-05-29 |  |  |  | 0.0u
Zo | 2021-05-30 |  |  |  | 0.0u
Ma | 2021-05-31 |  |  |  | 0.0u | Total:0.0u
Di | 2021-06-01 |  |  |  | 0.0u
Wo | 2021-06-02 |  |  |  | 0.0u
Do | 2021-06-03 |  |  |  | 0.0u
Vr | 2021-06-04 |  |  |  | 0.0u
Za | 2021-06-05 |  |  |  | 0.0u
Zo | 2021-06-06 |  |  |  | 0.0u
Ma | 2021-06-07 |  |  |  | 0.0u | Total:0.0u
Di | 2021-06-08 |  |  |  | 0.0u
Wo | 2021-06-09 |  |  |  | 0.0u
Do | 2021-06-10 |  |  |  | 0.0u
Vr | 2021-06-11 |  |  |  | 0.0u
Za | 2021-06-12 |  |  |  | 0.0u
Zo | 2021-06-13 |  |  |  | 0.0u
Ma | 2021-06-14 |  |  |  | 0.0u
Di | 2021-06-15 |  |  |  | 0.0u
Wo | 2021-06-16 |  |  |  | 0.0u
Do | 2021-06-17 |  |  |  | 0.0u
Vr | 2021-06-18 |  |  |  | 0.0u
 |  |  |  |  | Total hours:24.51666667u | 13.62037037%

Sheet: Database components
Number | Group | Name | Price | Units | Price/ Unit | Datasheet | Website
HC-04SR | Sensors | Distance sensor | €4.00 | 2 | €2.00
Laser diode |  |  | €8.00 | 3 | €2.67
test 1 |  |  | €2.00 | 1 | €2.00
test 2 |  |  | €3.00 | 1 | €3.00
test 3 |  |  |  |  | #DIV/0!

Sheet: Graphs
Material | Sum of Purchased quantity
HC-04SR | 78

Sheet: Costs
Material | Purchased quantity | Price/ Unit | Total Price | Used | Group
HC-04SR | 2 | €2.00 | €4.00 |  | Sensors
HC-04SR | 3 | €2.00 | €6.00 |  | Sensors
Laser diode | 1 | €2.67 | €2.67 |  | 0
HC-04SR | 5 | €2.00 | €10.00 |  | Sensors
HC-04SR | 6 | €2.00 | €12.00 |  | Sensors
HC-04SR | 7 | €2.00 | €14.00 |  | Sensors
test 1 | 8 | €2.00 | €16.00 |  | 0
test 2 | 9 | €3.00 | €27.00 |  | 0
HC-04SR | 10 | €2.00 | €20.00 |  | Sensors
HC-04SR | 11 | €2.00 | €22.00 |  | Sensors
HC-04SR | 12 | €2.00 | €24.00 |  | Sensors
Laser diode | 13 | €2.67 | €34.67 |  | 0

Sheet: Scan Matrix Keys
w1 | w2 | Note | Place Piano | w1 | w2 | Note | Place Piano
1 | 15 | DO1 | 1 | 5 | 15 | FAk4 | 8
1 | 14 | DOk1 |  | 5 | 14 | SOL4
1 | 13 | RE1 |  | 5 | 13 | SOLk4
1 | 12 | REk1 |  | 5 | 12 | LA4
1 | 11 | MI1 |  | 5 | 11 | LAk4
1 | 10 | FA1 |  | 5 | 10 | SI4
2 | 15 | FAk1 | 2 | 6 | 15 | DO4 | 7
2 | 14 | SOL1 |  | 6 | 14 | DOk4
2 | 13 | SOLk1 |  | 6 | 13 | RE4
2 | 12 | LA1 |  | 6 | 12 | REk4
2 | 11 | LAk1 |  | 6 | 11 | MI4
2 | 10 | SI1 |  | 6 | 10 | FA4
3 | 15 | FAk2 | 4 | 7 | 15 | FAk3 | 6
3 | 14 | SOL2 |  | 7 | 14 | SOL3
3 | 13 | SOLk2 |  | 7 | 13 | SOLk3
3 | 12 | LA2 |  | 7 | 12 | LA3
3 | 11 | LAk2 |  | 7 | 11 | LAk3
3 | 10 | SI2 |  | 7 | 10 | SI3
4 | 15 | DO5 | 9 | 8 | 15 | DO3 | 5
4 | 14 | / |  | 8 | 14 | DOk3
4 | 13 | / |  | 8 | 13 | RE3
4 | 12 | / |  | 8 | 12 | REk3
4 | 11 | / |  | 8 | 11 | MI3
4 | 10 | / |  | 8 | 10 | FA3
 |  |  |  | 9 | 15 | DO2 | 3
 |  |  |  | 9 | 14 | DOk2
 |  |  |  | 9 | 13 | RE2
 |  |  |  | 9 | 12 | REk2
 |  |  |  | 9 | 11 | MI2
 |  |  |  | 9 | 10 | FA2

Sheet: Proposal Orders
Group | Component | Price/Unit | Pieces | Verzending | Total Price | Website
Sensors | HC-SR04 | €3.65 | 2 | €6.95 | €14.25 | shorturl.at/bhIM8 (https://www.reichelt.com/be/nl/ontwikkelaarspanelen-ultrasone-afstandssensor-hc-sr04-debo-sen-ultra-p161487.html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)
Sensors | HC-SR04 | €1.10 | 2 | €2.17 | €4.37
Sensors | HC-SR04 x2 | €2.54 | 1 | €2.17 | €4.71
Sliders | RS60112-LIN100K | €3.13 | 8 | €6.95 | €31.99
Light | Laser diode | €0.93 | 2 | €4.09 | €5.95
Microcontroller | NXP LPC1114FBD48/302 | €3.12 | 1 | €4.95 | €8.07 | shorturl.at/dnsxA (https://benl.rs-online.com/web/p/microcontrollers/7413917?matchtype=&pla-414821074044&gclsrc=aw.ds)
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

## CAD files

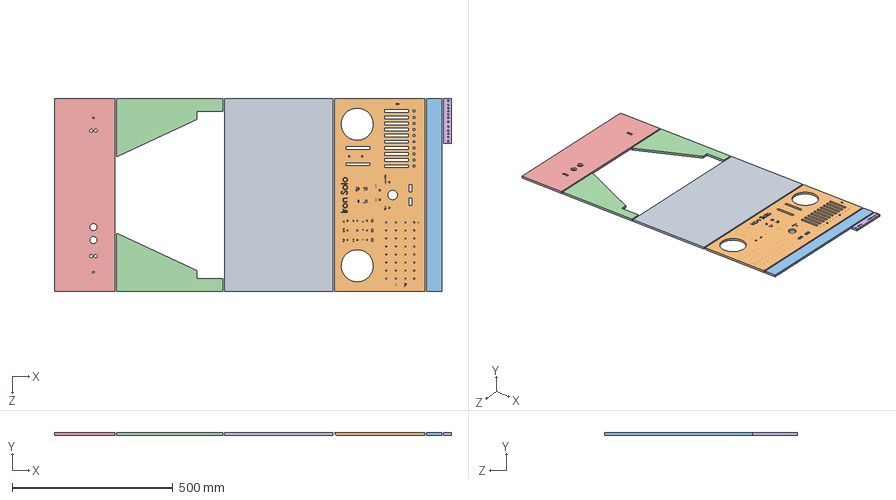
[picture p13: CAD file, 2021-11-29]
Practise Enterprise 1/Design/Houtplaat.SLDASM
1234.0 x 8.00 x 600.0 mm
ground panel
Main panel
front panel
side panel x 2
back panel
led panel

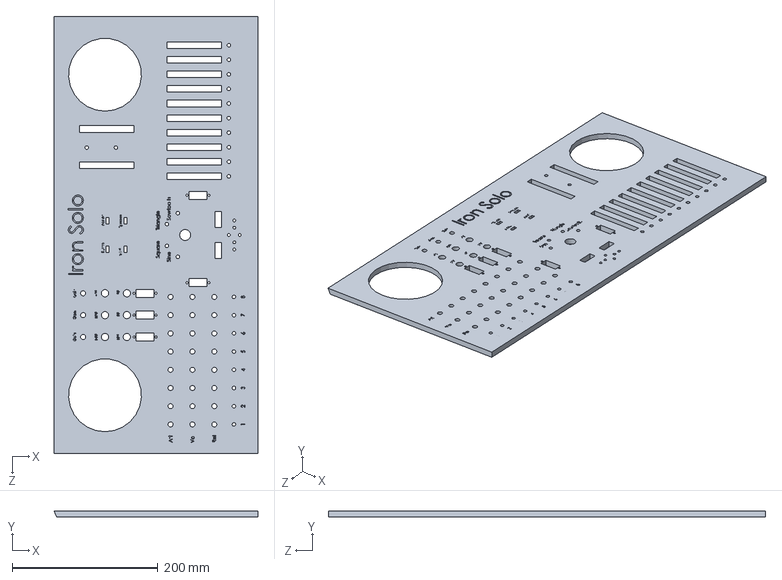
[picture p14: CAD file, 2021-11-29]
Practise Enterprise 1/Design/Main panel.SLDPRT
280.0 x 8.00 x 600.0 mm

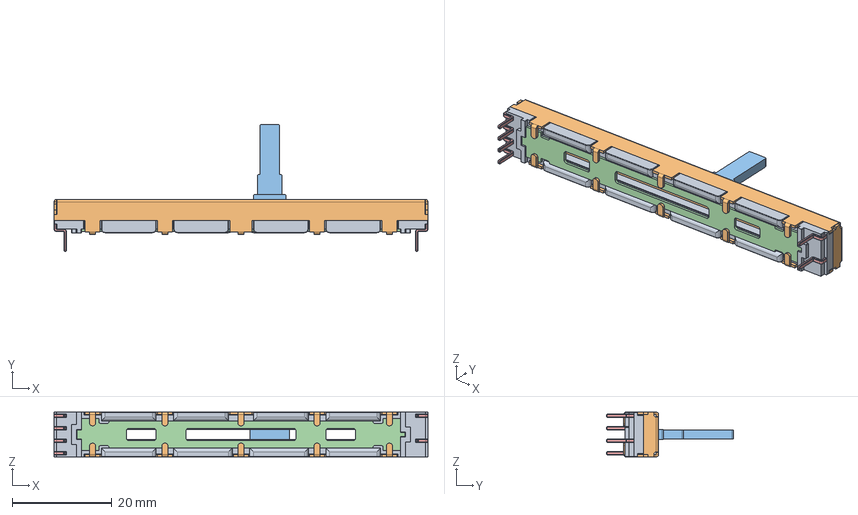
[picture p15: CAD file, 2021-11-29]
Practise Enterprise 1/Design/potentio_assem_asm.stp
75.0 x 25.4 x 9.00 mm
SLIDE_POTENTIOMETER_BODY
SLIDE_POTENTIOMETER_COVER
SLIDE_POTENTIOMETER_BAR
SLIDE_POTENTIOMETER_PLATE
SLIDE_POTENTIOMETER_PIN x 6

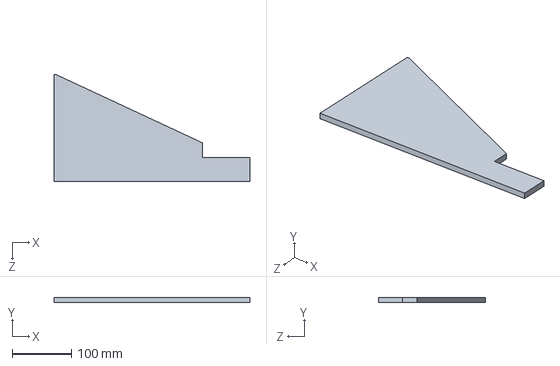
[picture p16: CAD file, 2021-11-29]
Practise Enterprise 1/Design/side panel.SLDPRT
330.0 x 8.00 x 180.0 mm

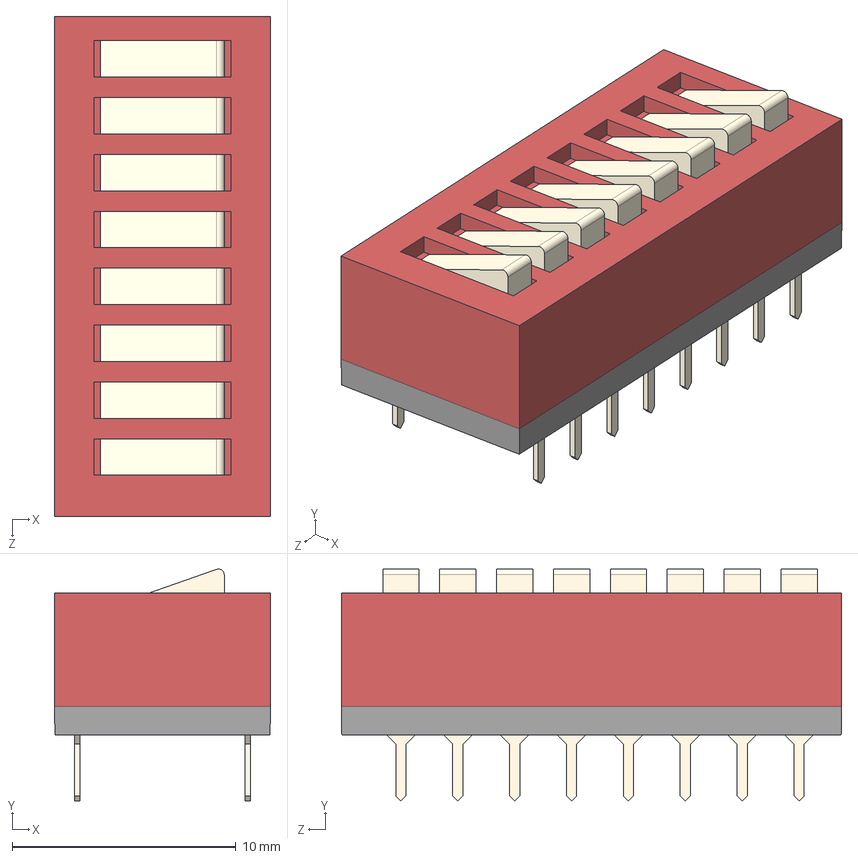
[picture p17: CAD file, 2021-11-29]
Practise Enterprise 1/Design/DIPSW16.STEP
9.65 x 10.4 x 22.4 mm

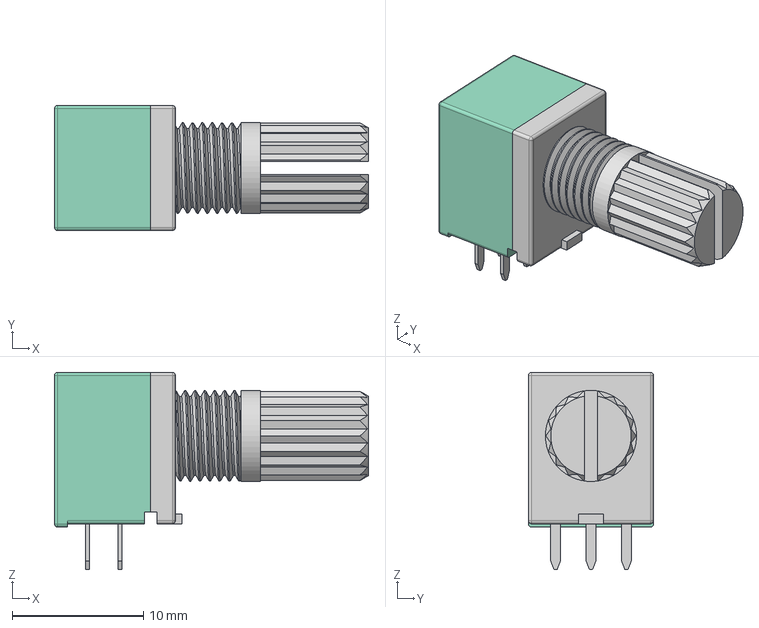
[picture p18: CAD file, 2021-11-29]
Practise Enterprise 1/Design/10K_DUPLEX_POT.step
23.9 x 9.54 x 15.1 mm

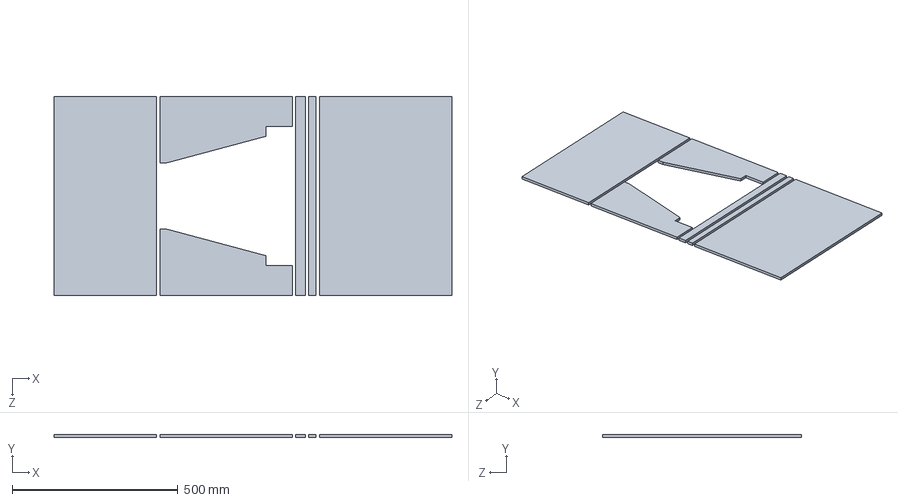
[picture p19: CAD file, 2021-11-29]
Practise Enterprise 1/Design/kuthout.SLDPRT
1200.0 x 10.0 x 600.0 mm

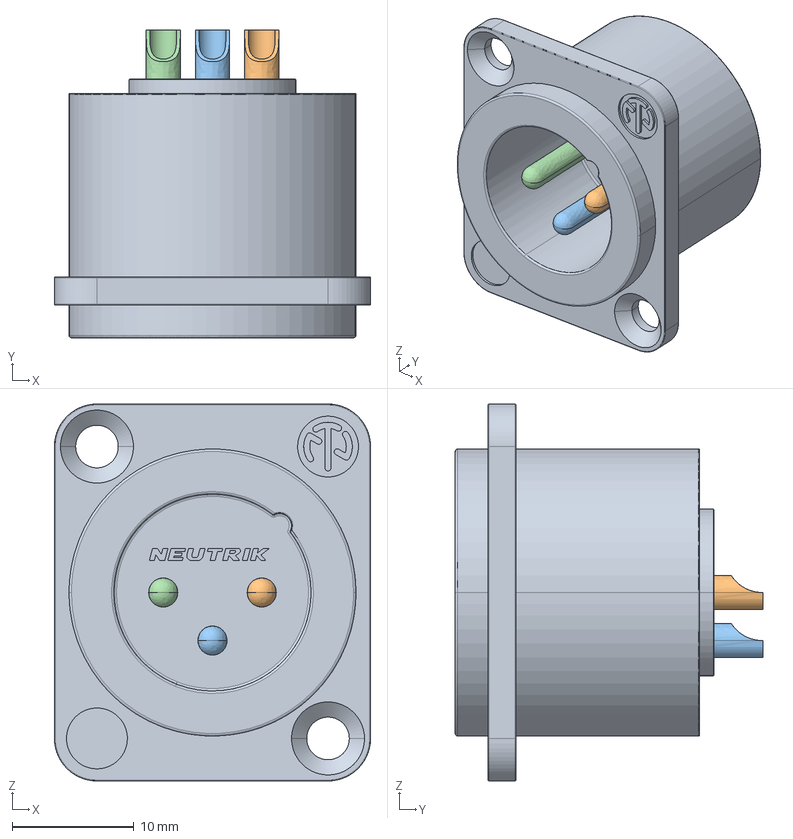
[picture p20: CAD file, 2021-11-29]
Practise Enterprise 1/Design/NC3MD-LX_01-GC-STEP.stp
26.0 x 25.3 x 31.0 mm

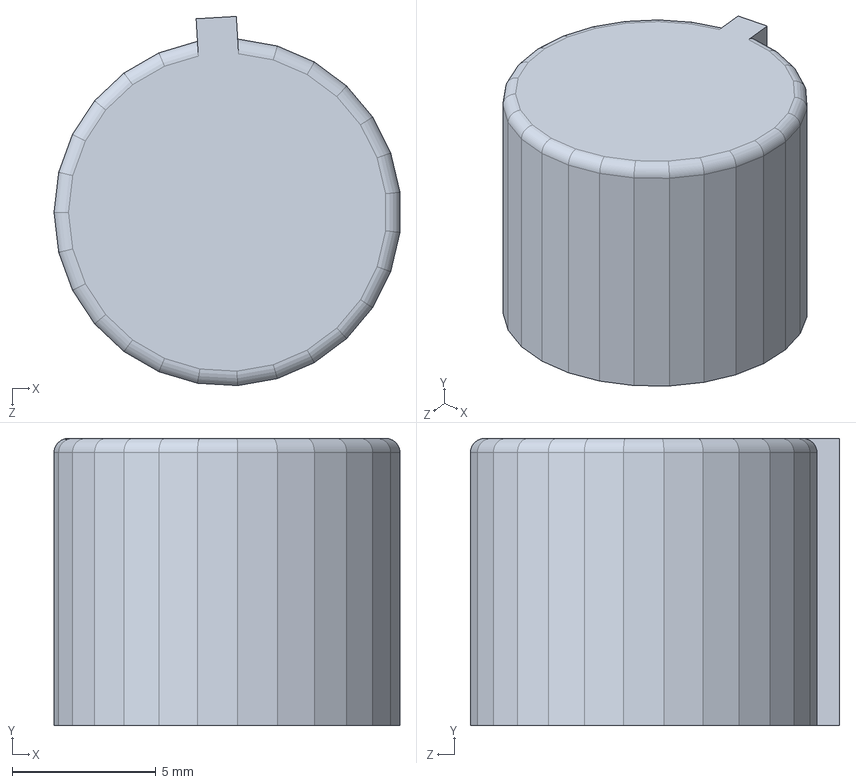
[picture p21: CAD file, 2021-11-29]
Practise Enterprise 1/Design/Pot.SLDPRT
12.0 x 10.0 x 12.8 mm

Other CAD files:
Practise Enterprise 1/Code/XC888/Tussentijds/one full note.obj
Practise Enterprise 1/Code/XC888/Definitief/Iron Solo Synthesizer.obj
Practise Enterprise 1/Code/XC888/Echt/IronSolo try.obj
Practise Enterprise 1/Code/XC888/Tussentijds/SendDDS.obj
Practise Enterprise 1/Code/XC888/Definitief/Lookup.obj
Practise Enterprise 1/Code/XC888/Tussentijds/Software SPI.obj
Practise Enterprise 1/Code/XC888/Tussentijds/DSSsend.obj
Practise Enterprise 1/Code/XC888/Tussentijds/Scanloops.obj
Practise Enterprise 1/Code/XC888/Tussentijds/Waveforselect.obj
Practise Enterprise 1/Code/XC888/Tussentijds/Leds op knop.obj
Practise Enterprise 1/Code/XC888/Tussentijds/Tryke.obj
Practise Enterprise 1/Design/Big pot.SLDPRT
Practise Enterprise 1/Design/EC11_rotary_encoder_knob.stp
Practise Enterprise 1/Design/EG1249.step
Practise Enterprise 1/Design/LED.SLDPRT
Practise Enterprise 1/Design/Main panel.SLDDRW
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

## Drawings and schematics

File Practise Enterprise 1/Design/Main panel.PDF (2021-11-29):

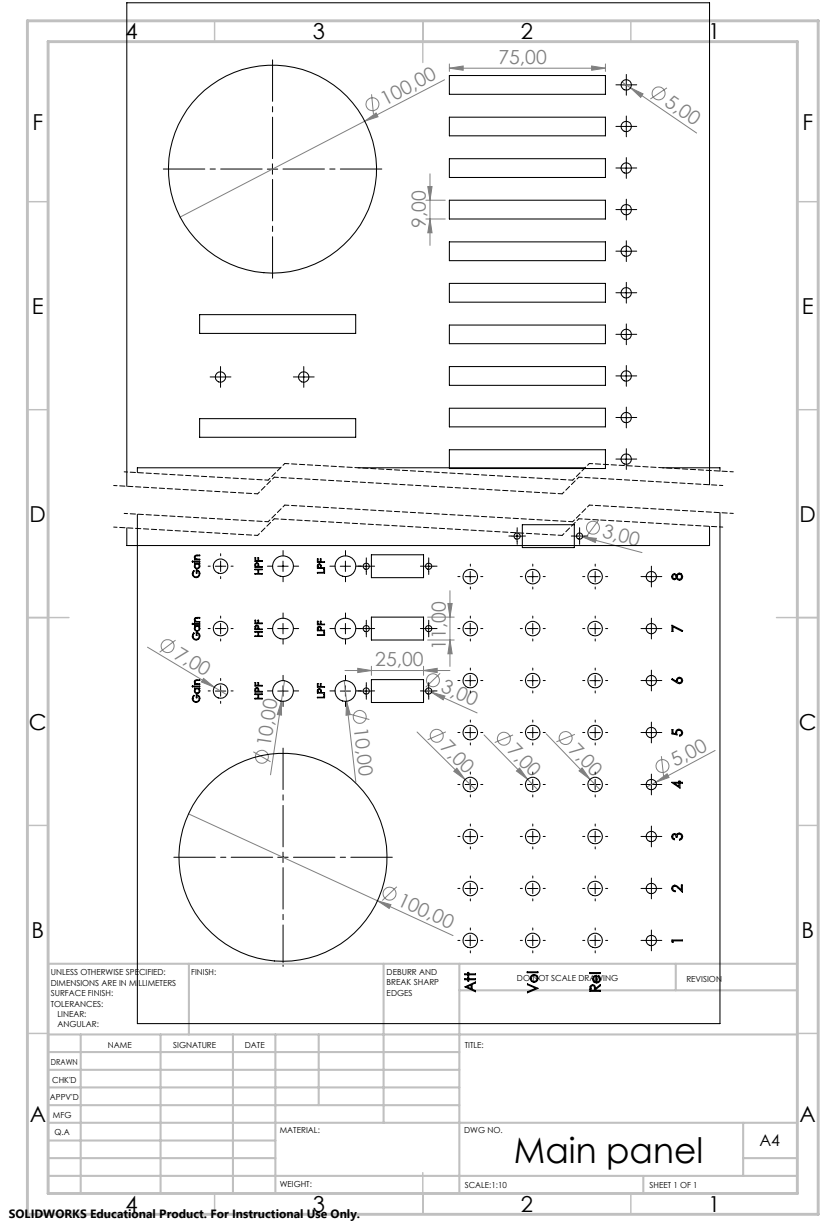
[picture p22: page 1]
FINISH:; DEBURR AND; BREAK SHARP; DO NOT SCALE DRAWING; REVISION; SCALE:1:10; SHEET 1 OF 1

UNLESS OTHERWISE SPECIFIED:
DIMENSIONS ARE IN MILLIMETERS
SURFACE FINISH:
TOLERANCES:
LINEAR:
ANGULAR:

NAME | SIGNATURE | DATE | | | | TITLE:

DRAWN
CHK'D
APPV'D
MFG
Q.A | | | | MATERIAL: | DWG NO. Main panel | A4

SOLIDWORKS Educational Product. For Instructional Use Only.

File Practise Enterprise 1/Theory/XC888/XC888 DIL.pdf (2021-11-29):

A

A

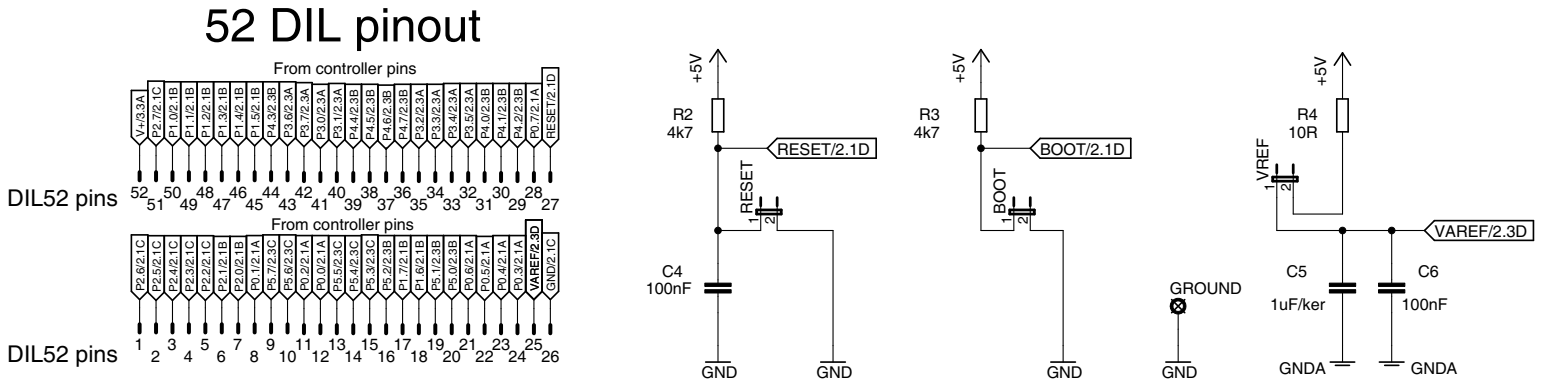
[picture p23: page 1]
GND; 1uF/ker; GNDA; 2RESET; 2VREF GROUND; RESET/2.1D; BOOT/2.1D; VAREF/2.3D; D. Pauwels; From controller pins; 52 DIL pinout; DIL52 pins

From controller pins

VAREF/2.3D VAREF/2.3D GND/2.1C

De Nayer Inst. XC888 DIL52

PINOUT, RESET, BOOT, VREF

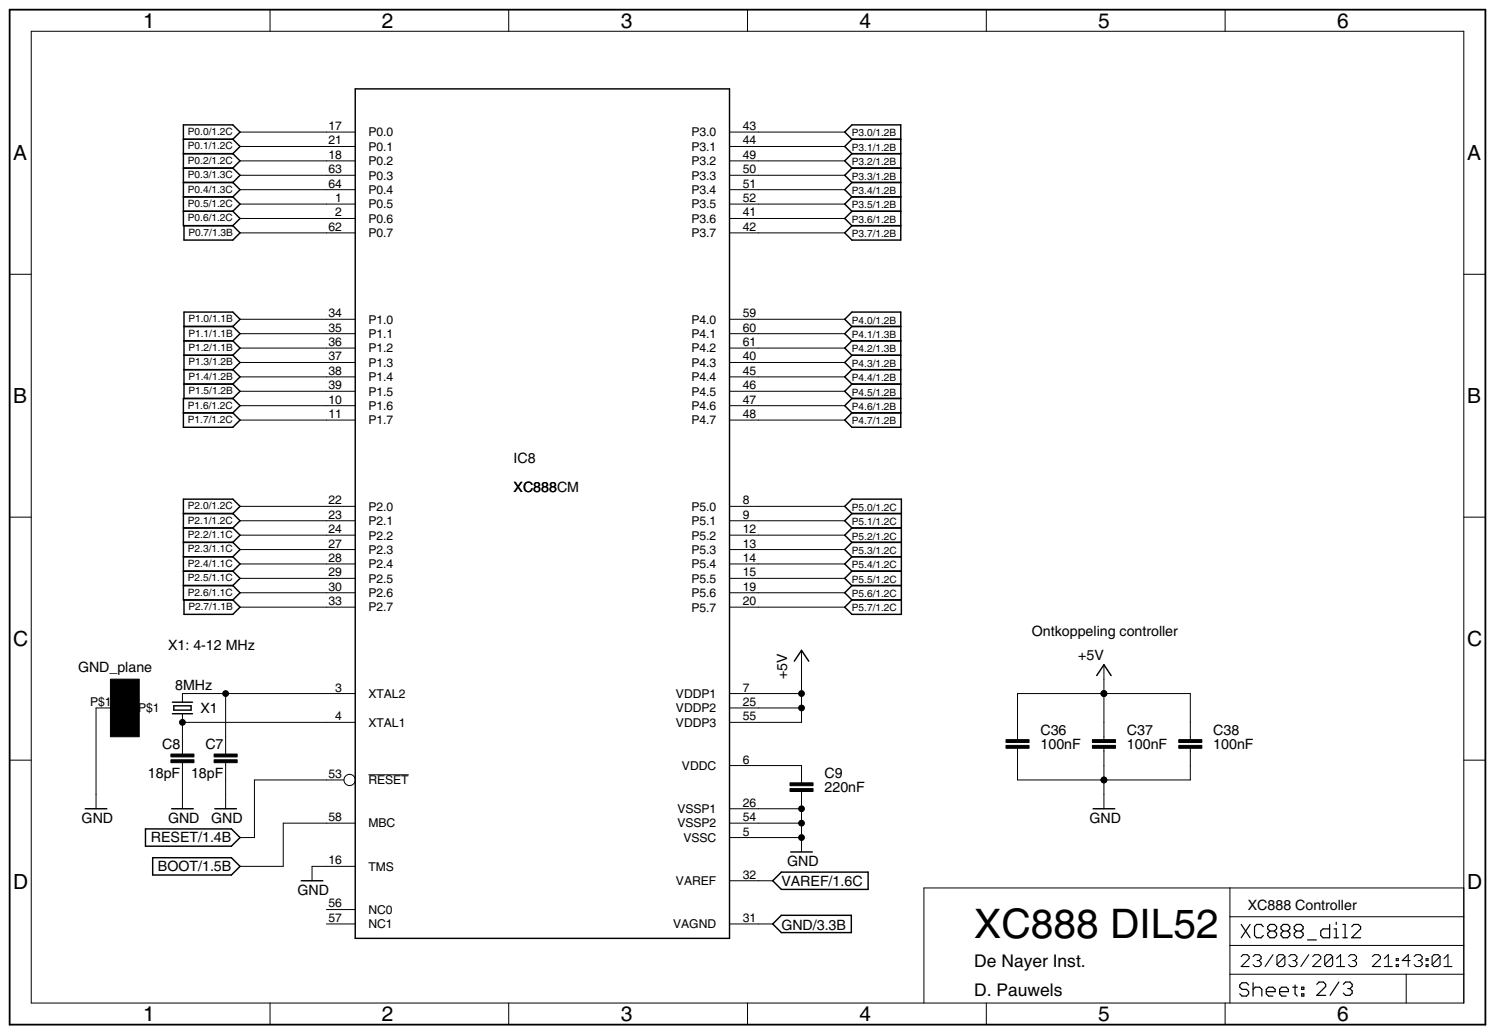
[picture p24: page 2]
220nF GND GND; +5V GND 8MHz; GND; 100nF +5V GND; GND C8; 20 VDDP1; 7 VDDP2; 25 VDDP3; 55 VDDC; 6 VSSP1; 26 VSSP2; 54 VSSC; 5 VAREF; 32 VAGND; TMS 16; MBC 58; RESET 53; XTAL1 4; XTAL2 3; RESET/1.4B BOOT/1.5B; VAREF/1.6C P0.0/1.2C P0.1/1.2C P0.2/1.2C P0.3/1.3C P0.4/1.3C P0.5/1.2C P0.6/1.2C P0.7/1.3B P1.0/1.1B P1.1/1.1B P1.2/1.1B P1.3/1.2B P1.4/1.2B P1.5/1.2B P1.6/1.2C P1.7/1.2C P2.0/1.2C P2.1/1.2C P2.2/1.1C P2.3/1.1C P2.4/1.1C P2.5/1.1C P2.6/1.1C P2.7/1.1B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

A

A

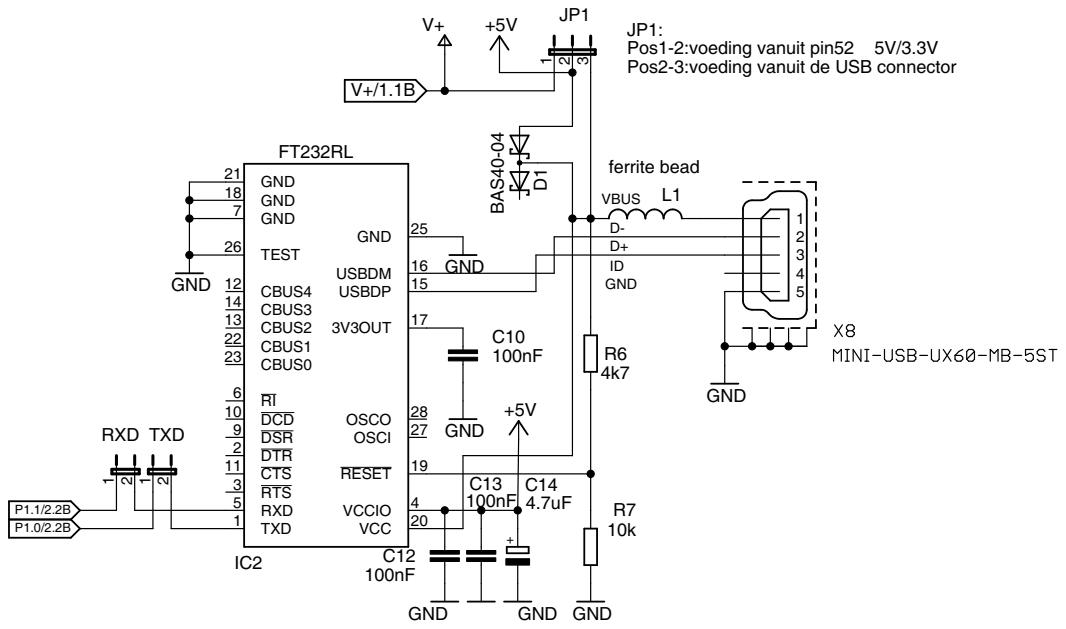
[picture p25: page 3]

Pos2-3:voeding vanuit de USB connector

USB connection/power select

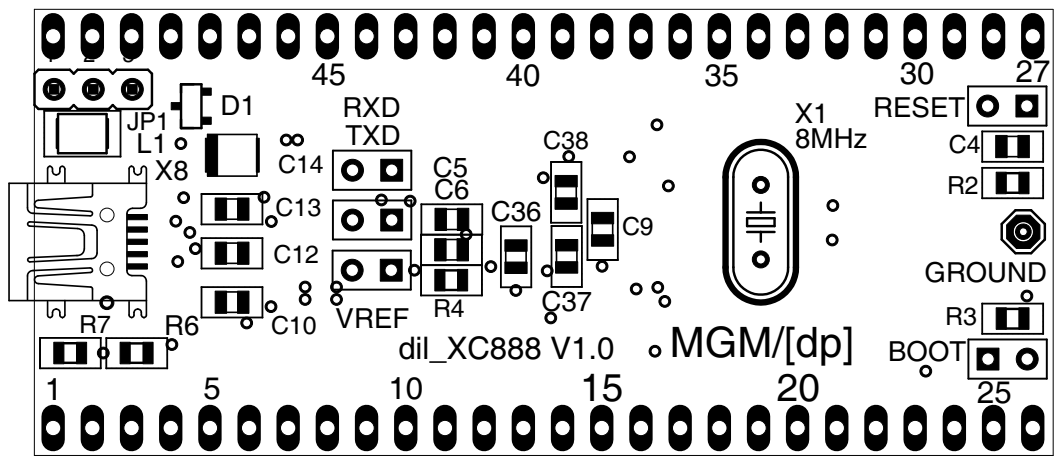
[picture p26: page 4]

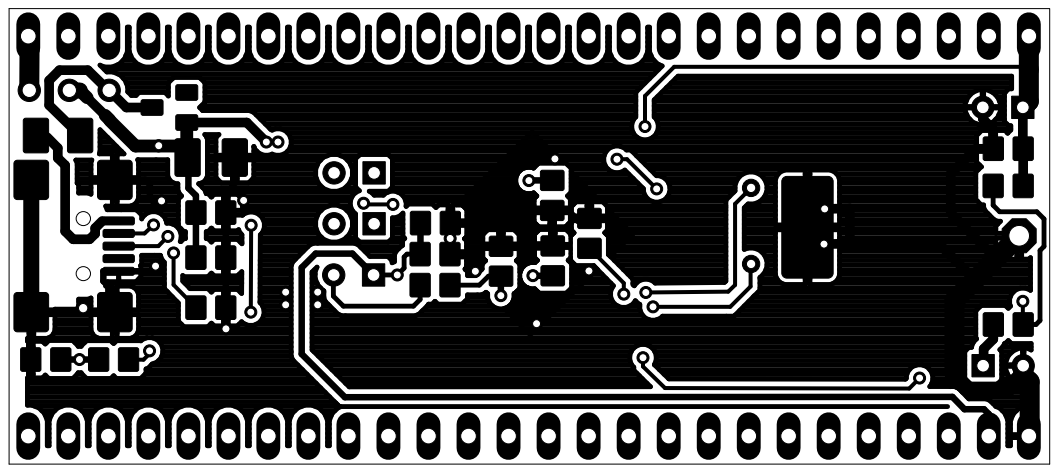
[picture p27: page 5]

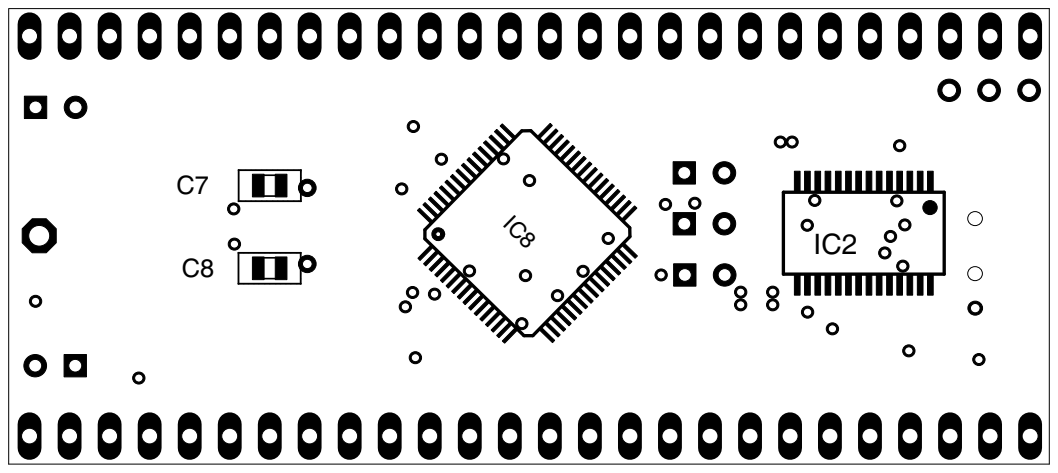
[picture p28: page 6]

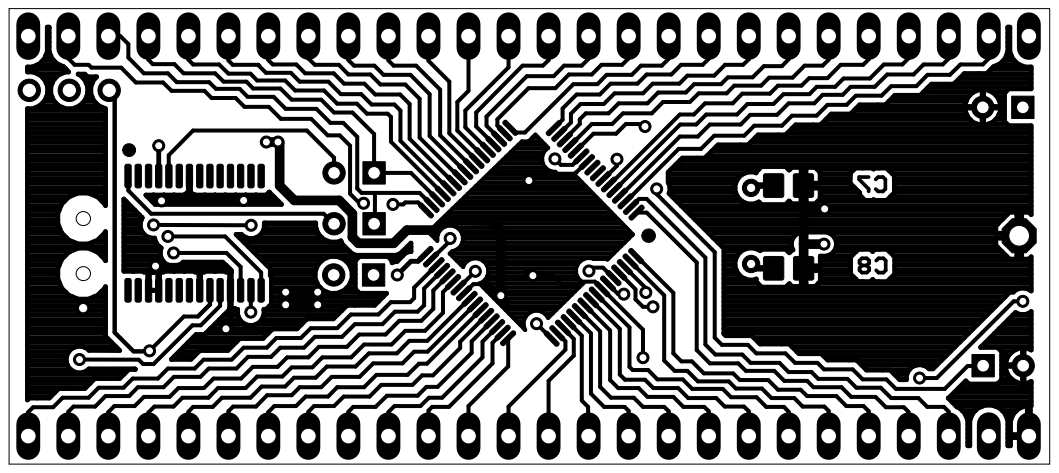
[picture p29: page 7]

P2.6
P2.5
P2.4
P2.3
P2.2
P2.1
P2.0
P0.1
P5.7
P5.6
P0.2
P0.0
P5.5
P5.4
P5.3
P5.2
P1.7
P1.6
P5.1
P5.0
P0.6
P0.5
P0.4
P0.3

# VAREF GND

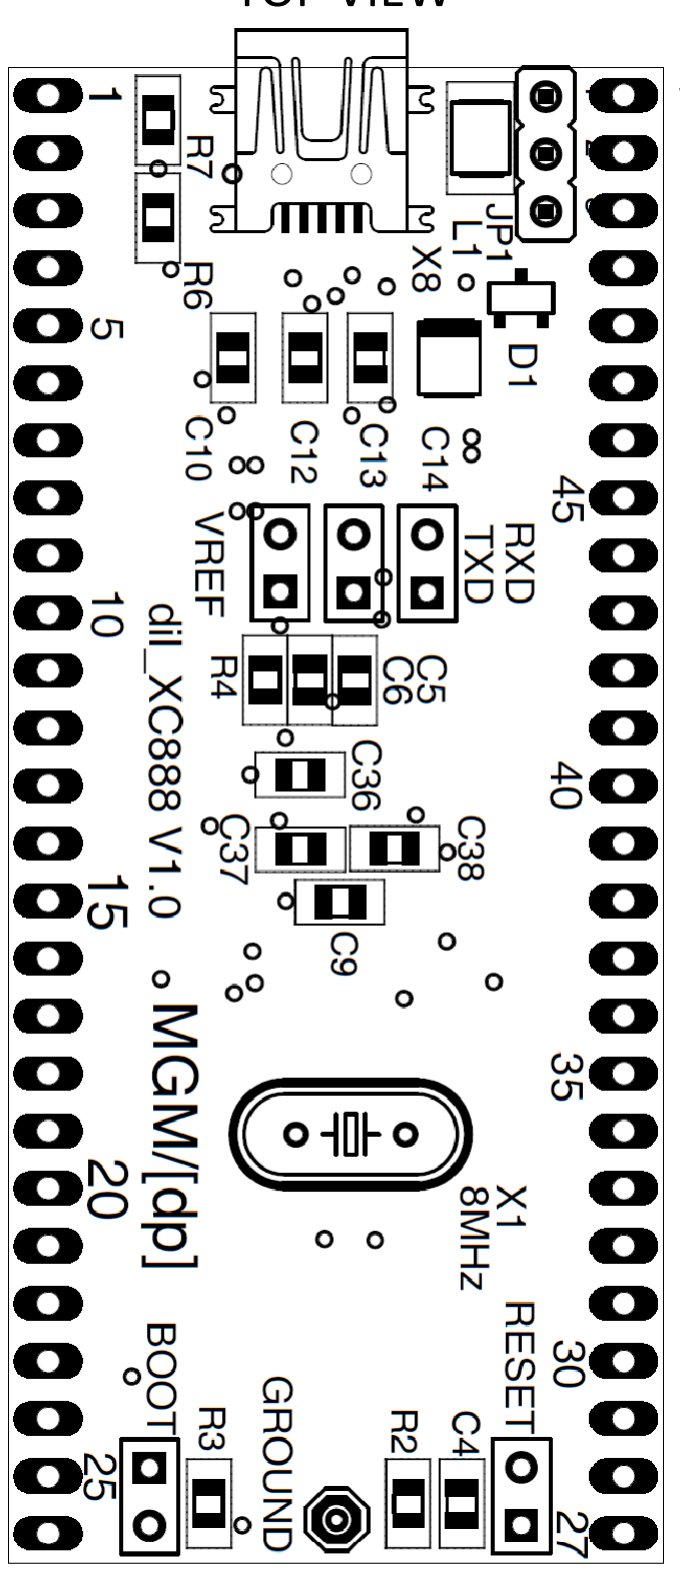
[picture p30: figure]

# V+ (5V/3.3V)

P2.7
P1.0
P1.1
P1.2
P1.3
P1.4
P1.5
P4.3
P3.6
P3.7
P3.0
P3.1
P4.4
P4.5
P4.6
P4.7
P3.2
P3.3
P3.4
P3.5
P4.0
P4.1
P4.2
P0.7

# RESET

# XC888 52 DIL PINOUT TOP VIEW

# Power select jumper

# USB powered

# V+(pin52) powered

# RxD/TxD jumpers

# Jumper for USB connection to PC

(P1.0/P1.1)

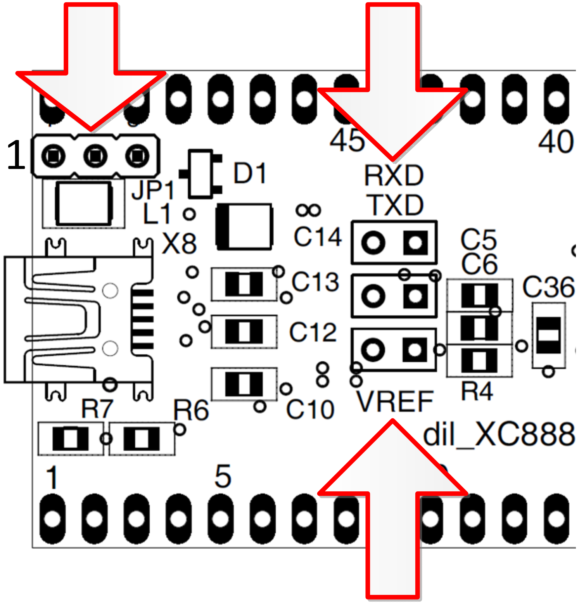
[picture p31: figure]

# Voltage reference select jumper

# Jumper for internal 5V/3.3V reference

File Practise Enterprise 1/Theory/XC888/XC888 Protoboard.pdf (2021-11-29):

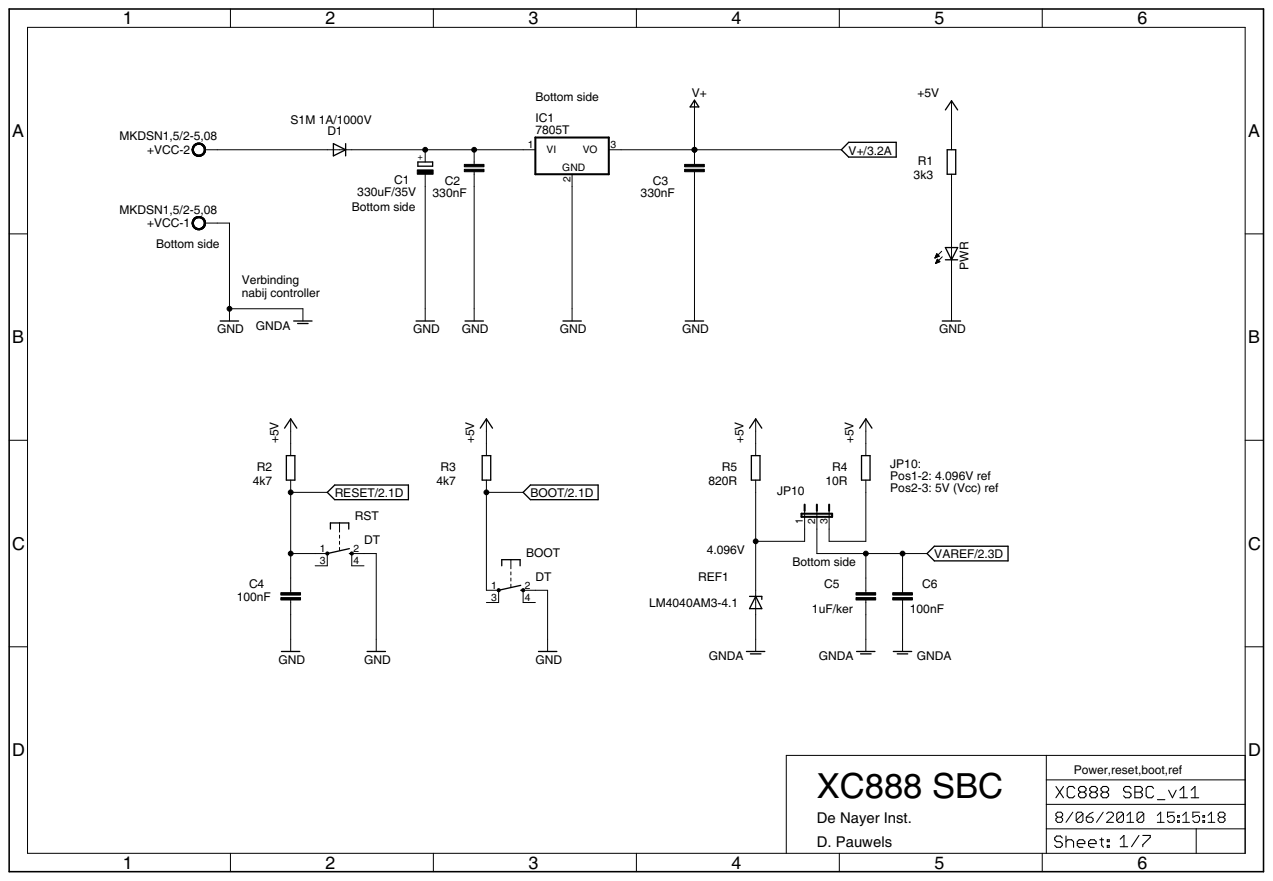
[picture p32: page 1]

Power,reset,boot,ref

D. Pauwels De Nayer Inst. XC888 SBC

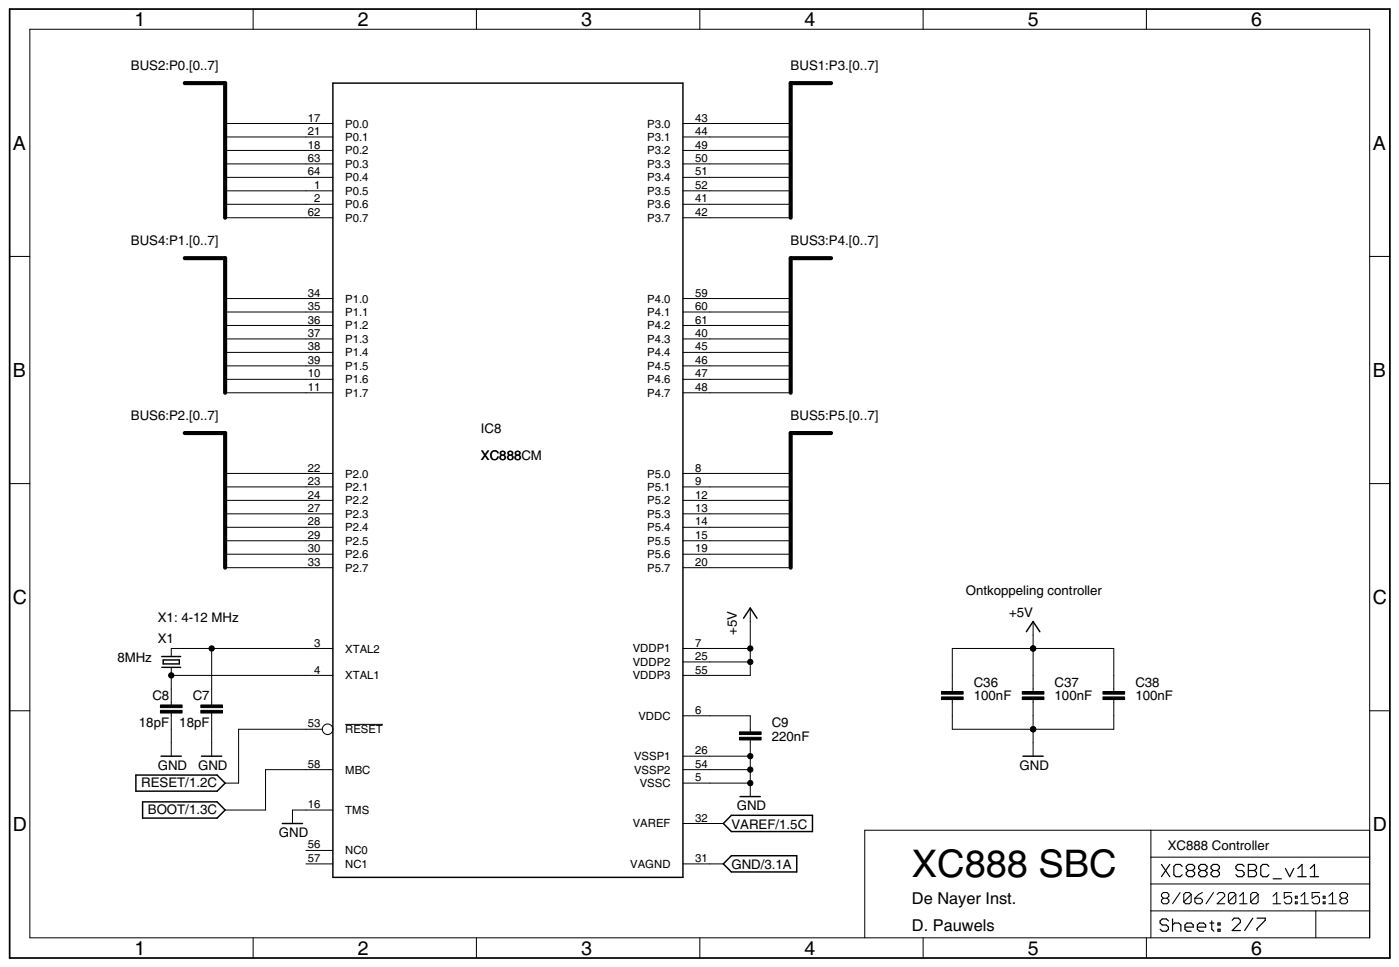
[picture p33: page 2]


Pos1-2:voeding vanuit de kroonsteen Pos2-3:voeding vanuit de USB connector

SPI
SPI-1 SPI-2 SPI-3 SPI-4 SPI-5 SPI-6

P0.5_RS232 | 8 DOUT

10 RIN

Bottom side

D. Pauwels De Nayer Inst. XC888 SBC



JP6: Extra I/O pin vb. Buzzer Bottom side

D. Pauwels De Nayer Inst. XC888 SBC


JP7: Pos1-2:Trimmer R23 op analoge ingang P2.4 Pos1-2:Leeg=Analoge ingang P2.4 beschikbaar op header2

2 | 15
3 | 14
4 | 13
5 | 12
6 | 11

Druktoetsen staan zodanig opgesteld
dat ze kunnen gebruikt worden als softswitches
in combinatie met een menu op het LCD scherm

+ - D. Pauwels De Nayer Inst. XC888 SBC

Rechtse druktoets Rechts-midden druktoets Links-midden druktoets Linkse druktoets

Pos1-2:Temp. sensor op analoge ingang P2.5 Pos1-2:Leeg=Analoge ingang P2.5 beschikbaar op header2

SWITCHES/Temp sensor/pot


JP9: Pos1-2:LEDs kunnen oplichten Pos1-2:Leeg=P3 wordt niet door de LEDs belast

D. Pauwels De Nayer Inst. XC888 SBC



T5087 V53/ Fu033 Fu7. 4 22-23-2031 22-23-2031 SPI 1402- 32- 22 22-23-2041 22-23-2031 k01 Z533 ML A57 ML BSU DCL 1CI 1C 1PJ 2X41C RS232 RS485 SPI C2I CAN LIN 91R 01CI 3H 4H H5 H2 1H 0H 01PJ 6CI * GND +9V 1 2 3 6PJ 01 12 01 12 10 12 10 12 01 12 01 12 1 2 3

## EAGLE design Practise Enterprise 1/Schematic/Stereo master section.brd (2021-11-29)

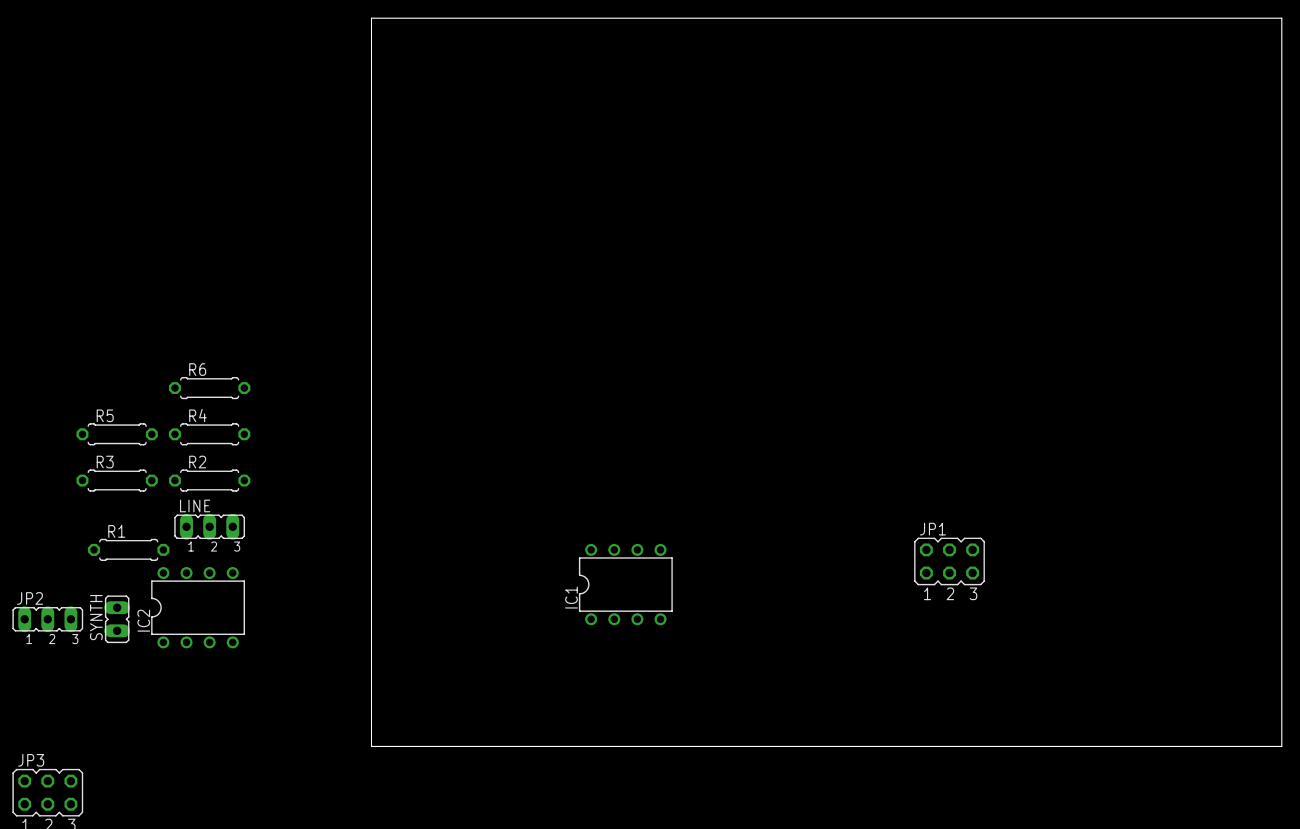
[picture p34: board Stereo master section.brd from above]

Board: 2 copper layers, 100.0 x 80.0 mm, 13 parts (0 on the bottom side), 13 nets, no tracks yet.

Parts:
IC1, IC2: LM358N; DIL08
JP1, JP3: JP3Q
JP2: JP2
LINE: JP2
R1, R2, R5, R6: 1k; 0207/7
R3, R4: 5k; 0207/7
SYNTH: JP1

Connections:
unnamed: R3.1, R4.1, SYNTH.2
unnamed: IC1.2, R1.1, R3.2
unnamed: IC2.6, JP1.3, R5.2
unnamed: IC1.6, R2.1, R4.2
unnamed: IC1.7, LINE.2, R2.2, R5.1
unnamed: IC2.2, JP1.4, R6.2
unnamed: LINE.3, R6.1
unnamed: IC2.7, JP1.5
unnamed: IC2.1, JP1.6
unnamed: IC1.8, IC2.8, JP2.3
unnamed: IC1.4, IC2.4, JP2.2
unnamed: IC1.3, IC1.5, IC2.3, IC2.5, JP1.1, JP1.2, JP2.1, SYNTH.1
unnamed: IC1.1, R1.2

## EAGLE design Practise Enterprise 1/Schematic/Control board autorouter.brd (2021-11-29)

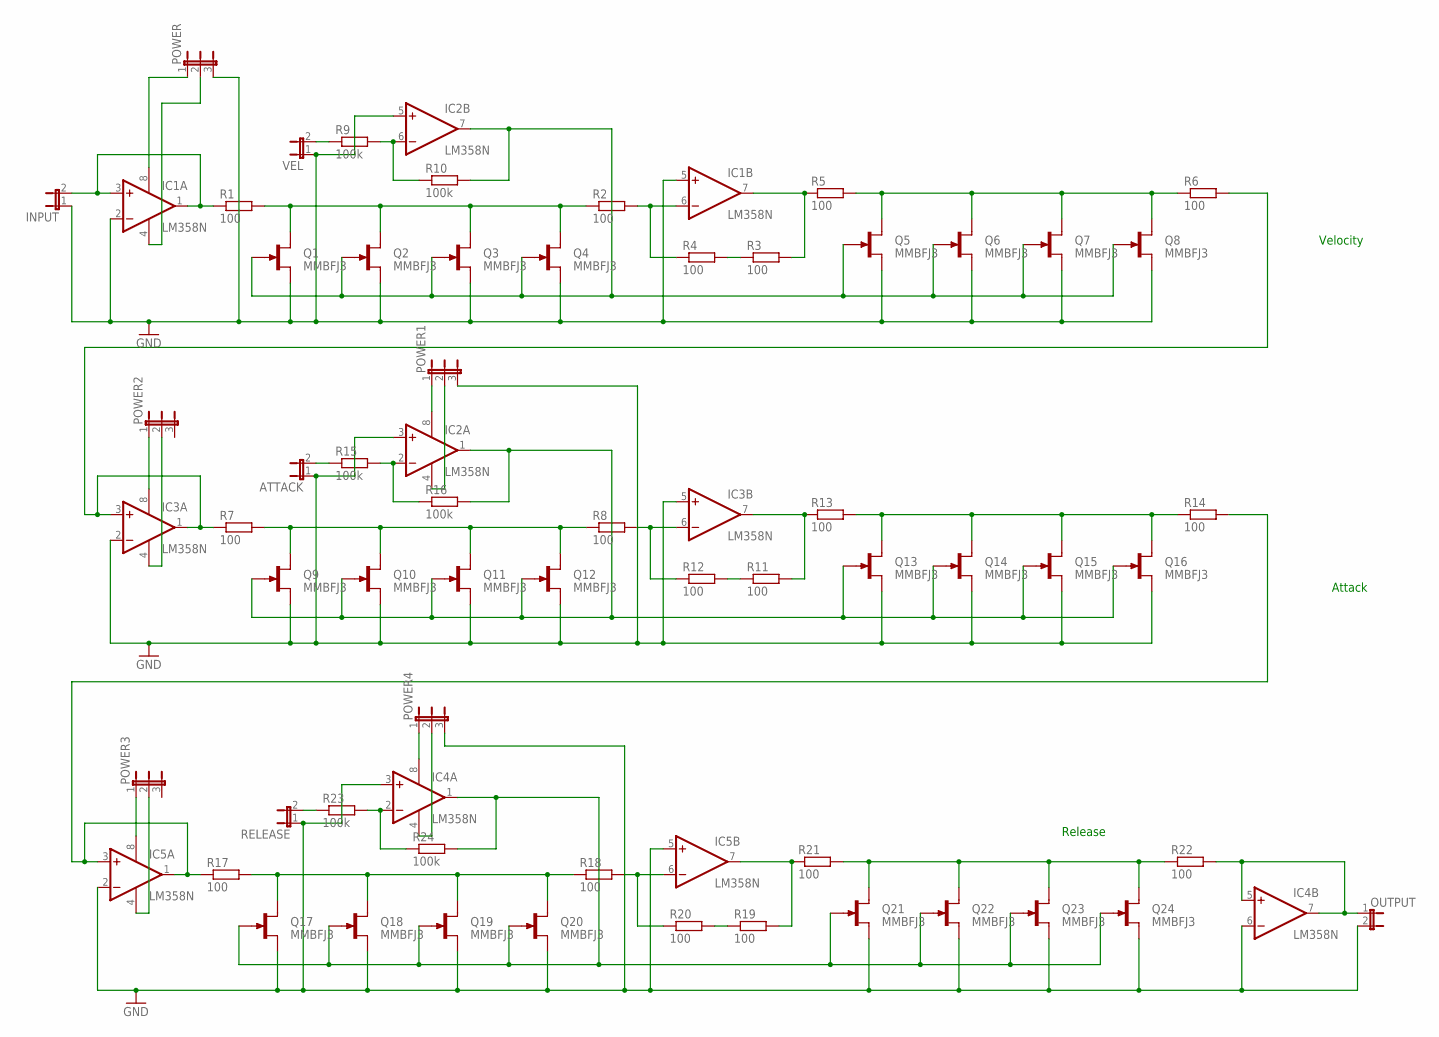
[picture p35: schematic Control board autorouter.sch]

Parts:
ATTACK: JP1E; JP1
IC1, IC2, IC3, IC4, IC5: LM358N; DIL08
INPUT: JP1E; JP1
OUTPUT: JP1E; JP1
POWER, POWER1, POWER2, POWER3, POWER4: JP2E; JP2
Q1, Q2, Q3, Q4, Q5, Q6, Q7, Q8, Q9, Q10, Q11, Q12, Q13, Q14, Q15, Q16, Q17, Q18, Q19, Q20, Q21, Q22, Q23, Q24: MMBFJ3; SOT23
R1, R2, R3, R4, R5, R6, R7, R8, R11, R12, R13, R14, R17, R18, R19, R20, R21, R22: 100; 0204/7
R9, R10, R15, R16, R23, R24: 100k; 0204/7
RELEASE: JP1E; JP1
VEL: JP1E; JP1

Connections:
22: Q13.1 (D), Q14.1 (D), Q15.1 (D), Q16.1 (D), R13.2, R14.1
CONTROL: IC2.7 (OUT), Q1.3 (G), Q2.3 (G), Q3.3 (G), Q4.3 (G), Q5.3 (G), Q6.3 (G), Q7.3 (G), Q8.3 (G), R10.2
CONTROL1: IC2.1 (OUT), Q9.3 (G), Q10.3 (G), Q11.3 (G), Q12.3 (G), Q13.3 (G), Q14.3 (G), Q15.3 (G), Q16.3 (G), R16.2
CONTROL2: IC4.1 (OUT), Q17.3 (G), Q18.3 (G), Q19.3 (G), Q20.3 (G), Q21.3 (G), Q22.3 (G), Q23.3 (G), Q24.3 (G), R24.2
GND: ATTACK.1, IC1.2 (-IN), IC1.5 (+IN), IC2.3 (+IN), IC2.5 (+IN), IC3.2 (-IN), IC3.5 (+IN), IC4.3 (+IN), IC4.6 (-IN), IC5.2 (-IN), IC5.5 (+IN), INPUT.1, OUTPUT.2, POWER.3, POWER1.3, POWER4.3, Q1.2 (S), Q2.2 (S), Q3.2 (S), Q4.2 (S), Q5.2 (S), Q6.2 (S), Q7.2 (S), Q8.2 (S), Q9.2 (S), Q10.2 (S), Q11.2 (S), Q12.2 (S), Q13.2 (S), Q14.2 (S), Q15.2 (S), Q16.2 (S), Q17.2 (S), Q18.2 (S), Q19.2 (S), Q20.2 (S), Q21.2 (S), Q22.2 (S), Q23.2 (S), Q24.2 (S), RELEASE.1, VEL.1
unnamed: IC4.8 (V+), POWER4.1
unnamed: IC1.8 (V+), POWER.1
unnamed: IC1.6 (-IN), R2.2, R4.1
unnamed: IC1.1 (OUT), IC1.3 (+IN), INPUT.2, R1.1
unnamed: R3.1, R4.2
unnamed: IC4.4 (V-), POWER4.2
unnamed: IC1.7 (OUT), R3.2, R5.1
unnamed: R9.1, VEL.2
unnamed: IC3.1 (OUT), IC3.3 (+IN), R6.2, R7.1
unnamed: IC5.8 (V+), POWER3.1
unnamed: IC2.6 (-IN), R9.2, R10.1
unnamed: IC4.5 (+IN), IC4.7 (OUT), OUTPUT.1, R22.2
unnamed: IC5.4 (V-), POWER3.2
unnamed: IC3.6 (-IN), R8.2, R12.1
unnamed: R11.1, R12.2
unnamed: IC3.7 (OUT), R11.2, R13.1
unnamed: IC3.8 (V+), POWER2.1
unnamed: IC5.1 (OUT), IC5.3 (+IN), R14.2, R17.1
unnamed: ATTACK.2, R15.1
unnamed: IC2.2 (-IN), R15.2, R16.1
unnamed: IC3.4 (V-), POWER2.2
unnamed: IC2.8 (V+), POWER1.1
unnamed: IC1.4 (V-), POWER.2
unnamed: IC2.4 (V-), POWER1.2
unnamed: IC5.6 (-IN), R18.2, R20.1
unnamed: R19.1, R20.2
unnamed: IC5.7 (OUT), R19.2, R21.1
unnamed: R23.1, RELEASE.2
unnamed: IC4.2 (-IN), R23.2, R24.1
NET11: Q1.1 (D), Q2.1 (D), Q3.1 (D), Q4.1 (D), R1.2, R2.1
NET12: Q5.1 (D), Q6.1 (D), Q7.1 (D), Q8.1 (D), R5.2, R6.1
NET21: Q9.1 (D), Q10.1 (D), Q11.1 (D), Q12.1 (D), R7.2, R8.1
NET31: Q17.1 (D), Q18.1 (D), Q19.1 (D), Q20.1 (D), R17.2, R18.1
NET32: Q21.1 (D), Q22.1 (D), Q23.1 (D), Q24.1 (D), R21.2, R22.1

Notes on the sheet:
Velocity
Attack
Release

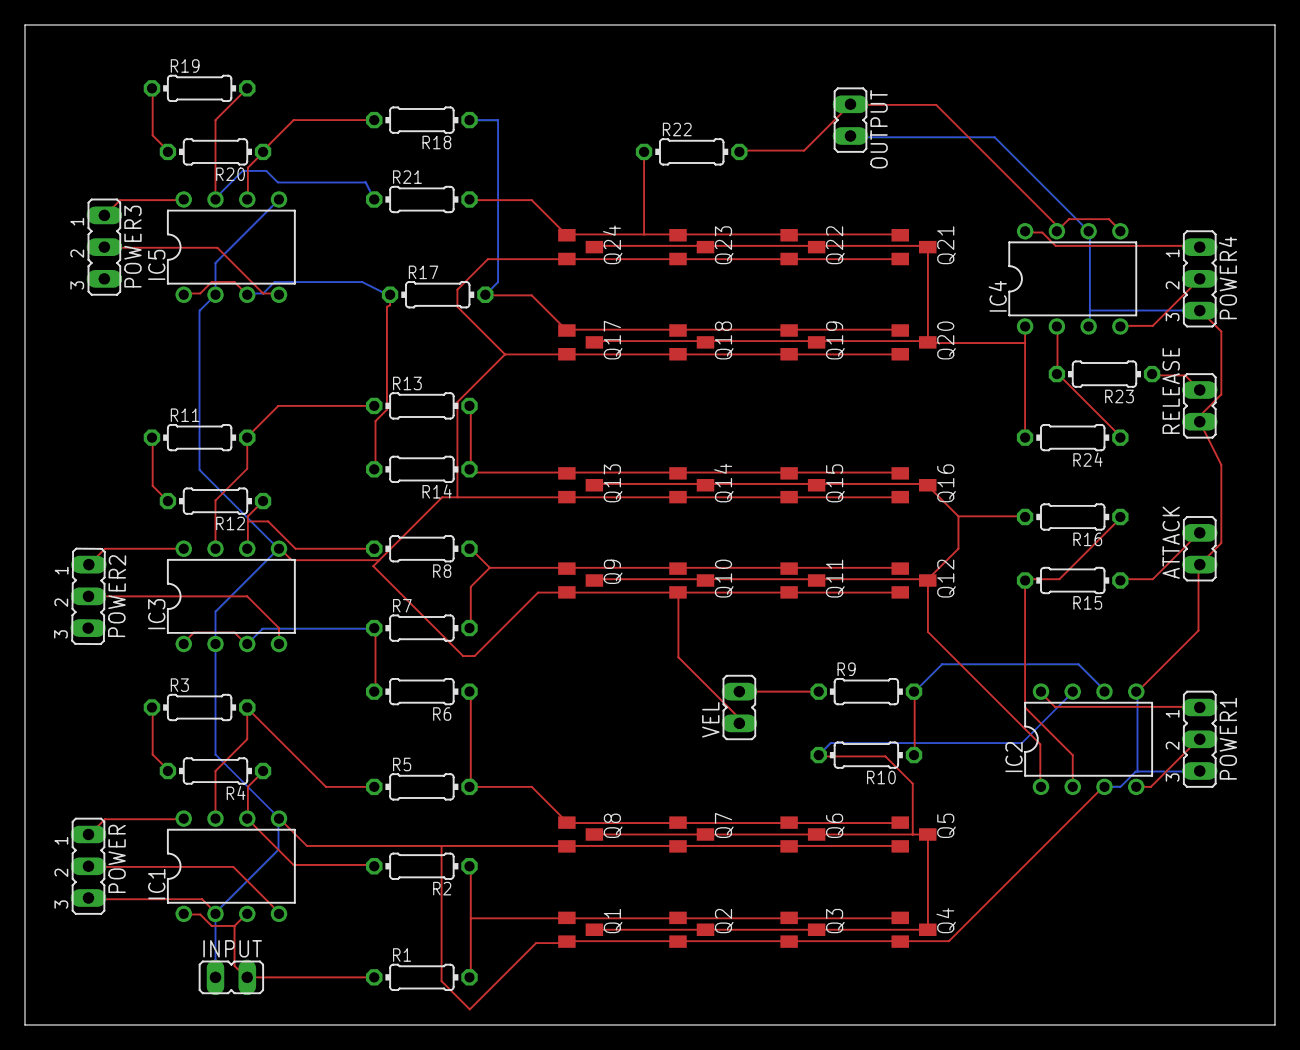
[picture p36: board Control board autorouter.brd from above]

Board: 2 copper layers, 100.0 x 80.0 mm, 63 parts (0 on the bottom side), 39 nets.

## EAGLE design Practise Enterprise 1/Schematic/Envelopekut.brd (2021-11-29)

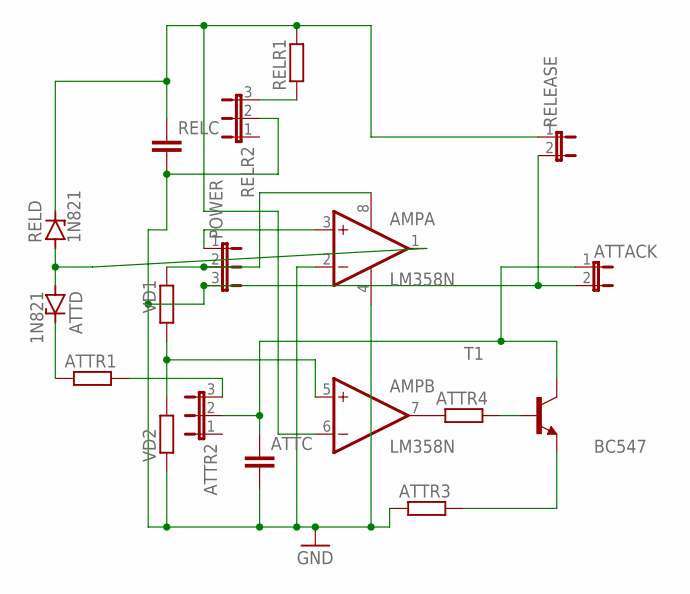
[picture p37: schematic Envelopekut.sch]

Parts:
AMP: LM358N; DIL08
ATTACK: JP1E; JP1
ATTC: C-EU025-025X050; C025-025X050
ATTD: 1N821; DO35Z10
ATTR1, ATTR3, ATTR4: R-EU_0207/10; 0207/10
ATTR2: JP2E; JP2
POWER: JP2E; JP2
RELC: C-EU025-025X050; C025-025X050
RELD: 1N821; DO35Z10
RELEASE: JP1E; JP1
RELR1: R-EU_0207/10; 0207/10
RELR2: JP2E; JP2
T1: BC547; TO92
VD1, VD2: R-EU_0207/10; 0207/10

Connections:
GND: AMP.2 (-IN), AMP.4 (V-), ATTACK.2, ATTC.2, ATTR3.1, POWER.3, RELC.2, RELEASE.2, RELR2.2, VD2.1
unnamed: AMP.5 (+IN), VD1.1, VD2.2
unnamed: AMP.7 (OUT), ATTR4.1
unnamed: ATTR4.2, T1.2 (B)
unnamed: ATTR1.2, ATTR2.3
unnamed: ATTR3.2, T1.1 (E)
unnamed: ATTACK.1, ATTC.1, ATTR2.2, T1.3 (C)
unnamed: ATTD.C, ATTR1.1
unnamed: AMP.1 (OUT), ATTD.A, RELD.A
unnamed: AMP.8 (V+), POWER.2, VD1.2
unnamed: AMP.3 (+IN), POWER.1
unnamed: AMP.6 (-IN), RELC.1, RELD.C, RELEASE.1, RELR1.2
unnamed: RELR1.1, RELR2.3

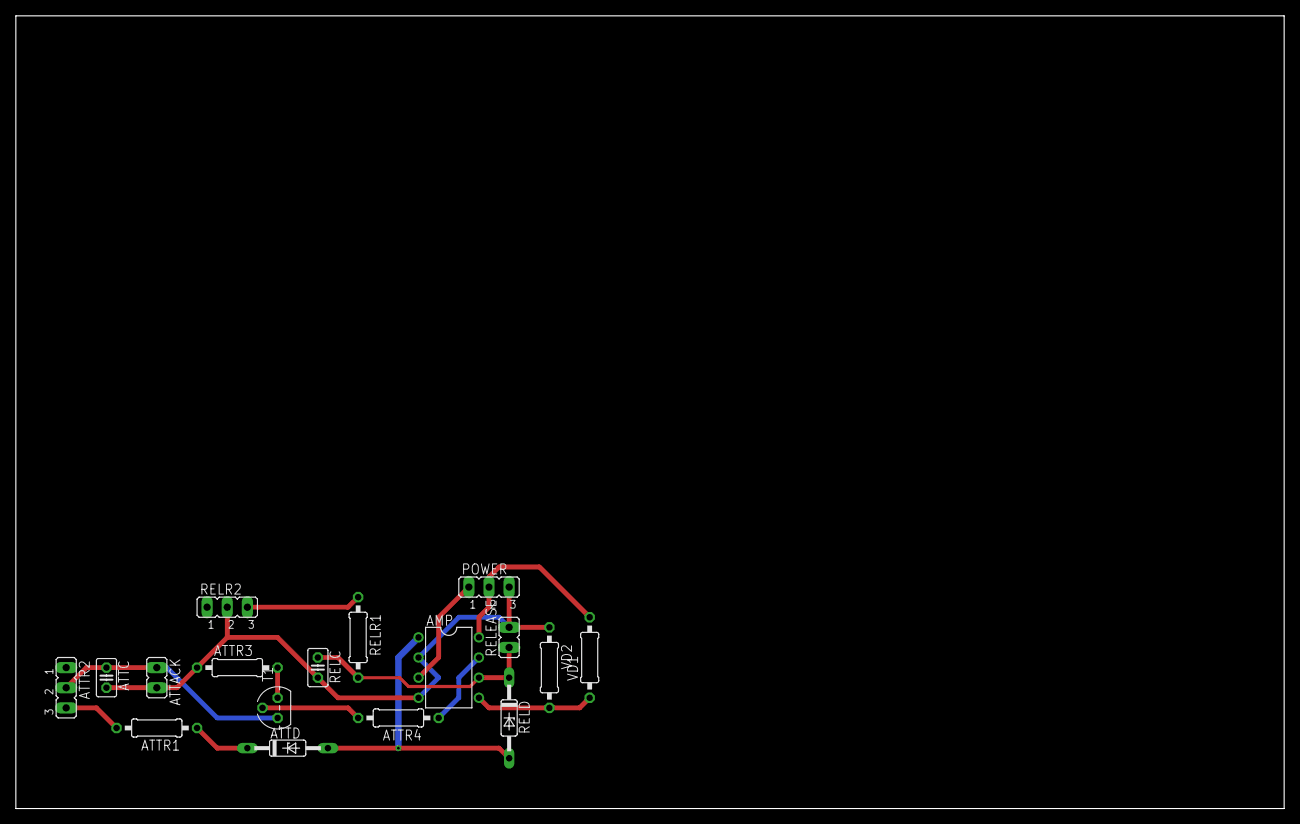
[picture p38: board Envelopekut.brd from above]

Board: 2 copper layers, 160.0 x 100.0 mm, 17 parts (0 on the bottom side), 13 nets.

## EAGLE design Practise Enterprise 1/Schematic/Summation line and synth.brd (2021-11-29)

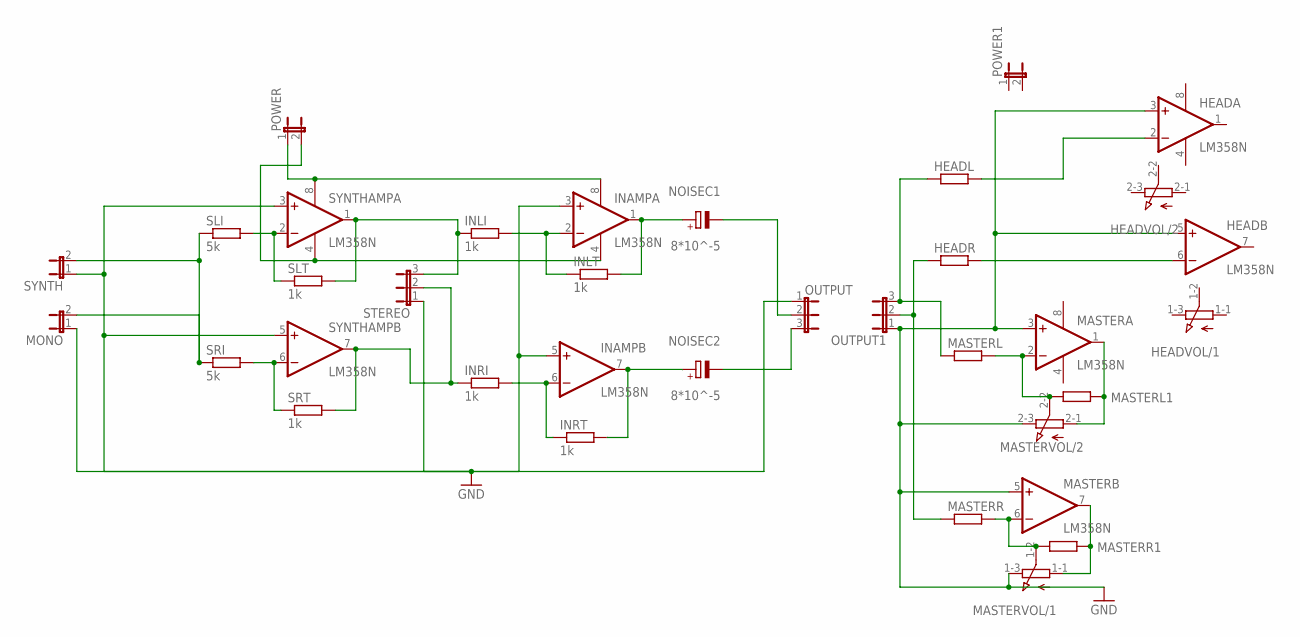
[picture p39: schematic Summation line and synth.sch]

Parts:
HEAD: LM358N; DIL08
HEADL: R-EU_0207/7; 0207/7
HEADR: R-EU_0207/7; 0207/7
HEADVOL: 3RP/1610G
INAMP: LM358N; DIL08
INLI: 1k; 0207/7
INLT: 1k; 0207/7
INRI: 1k; 0207/7
INRT: 1k; 0207/7
MASTER: LM358N; DIL08
MASTERL, MASTERL1: R-EU_0207/7; 0207/7
MASTERR, MASTERR1: R-EU_0207/7; 0207/7
MASTERVOL: 3RP/1610G
MONO: JP1E; JP1
NOISEC1, NOISEC2: 8*10^-5; E5-5
OUTPUT, OUTPUT1: JP2E; JP2
POWER, POWER1: JP1E; JP1
SLI: 5k; 0207/7
SLT: 1k; 0207/7
SRI: 5k; 0207/7
SRT: 1k; 0207/7
STEREO: JP2E; JP2
SYNTH: JP1E; JP1
SYNTHAMP: LM358N; DIL08

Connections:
GND: HEAD.3 (+IN), HEAD.5 (+IN), INAMP.3 (+IN), INAMP.5 (+IN), MASTER.3 (+IN), MASTER.5 (+IN), MASTERVOL.1-3 (E), MASTERVOL.2-3 (E), MONO.1, OUTPUT.1, OUTPUT1.1, STEREO.1, SYNTH.1, SYNTHAMP.3 (+IN), SYNTHAMP.5 (+IN)
unnamed: INAMP.4 (V-), POWER.2, SYNTHAMP.4 (V-)
unnamed: SLI.2, SLT.1, SYNTHAMP.2 (-IN)
unnamed: INAMP.6 (-IN), INRI.2, INRT.1
unnamed: SRI.2, SRT.1, SYNTHAMP.6 (-IN)
unnamed: INRI.1, SRT.2, STEREO.2, SYNTHAMP.7 (OUT)
unnamed: INAMP.2 (-IN), INLI.2, INLT.1
unnamed: INAMP.8 (V+), POWER.1, SYNTHAMP.8 (V+)
unnamed: INLI.1, SLT.2, STEREO.3, SYNTHAMP.1 (OUT)
unnamed: INAMP.7 (OUT), INRT.2, NOISEC2.+
unnamed: INAMP.1 (OUT), INLT.2, NOISEC1.+
unnamed: NOISEC1.-, OUTPUT.2
unnamed: NOISEC2.-, OUTPUT.3
unnamed: MASTER.2 (-IN), MASTERL.2, MASTERL1.1, MASTERVOL.2-2 (S)
unnamed: HEADL.1, MASTERL.1, OUTPUT1.3
unnamed: HEAD.2 (-IN), HEADL.2
unnamed: HEAD.6 (-IN), HEADR.2
unnamed: HEADR.1, MASTERR.1, OUTPUT1.2
unnamed: MASTER.6 (-IN), MASTERR.2, MASTERR1.1, MASTERVOL.1-2 (S)
unnamed: MASTER.7 (OUT), MASTERR1.2, MASTERVOL.1-1 (A)
unnamed: MASTER.1 (OUT), MASTERL1.2, MASTERVOL.2-1 (A)
SYNTHIN: MONO.2, SLI.1, SRI.1, SYNTH.2
V+: HEAD.8 (V+), MASTER.8 (V+)
V-: HEAD.4 (V-), MASTER.4 (V-)

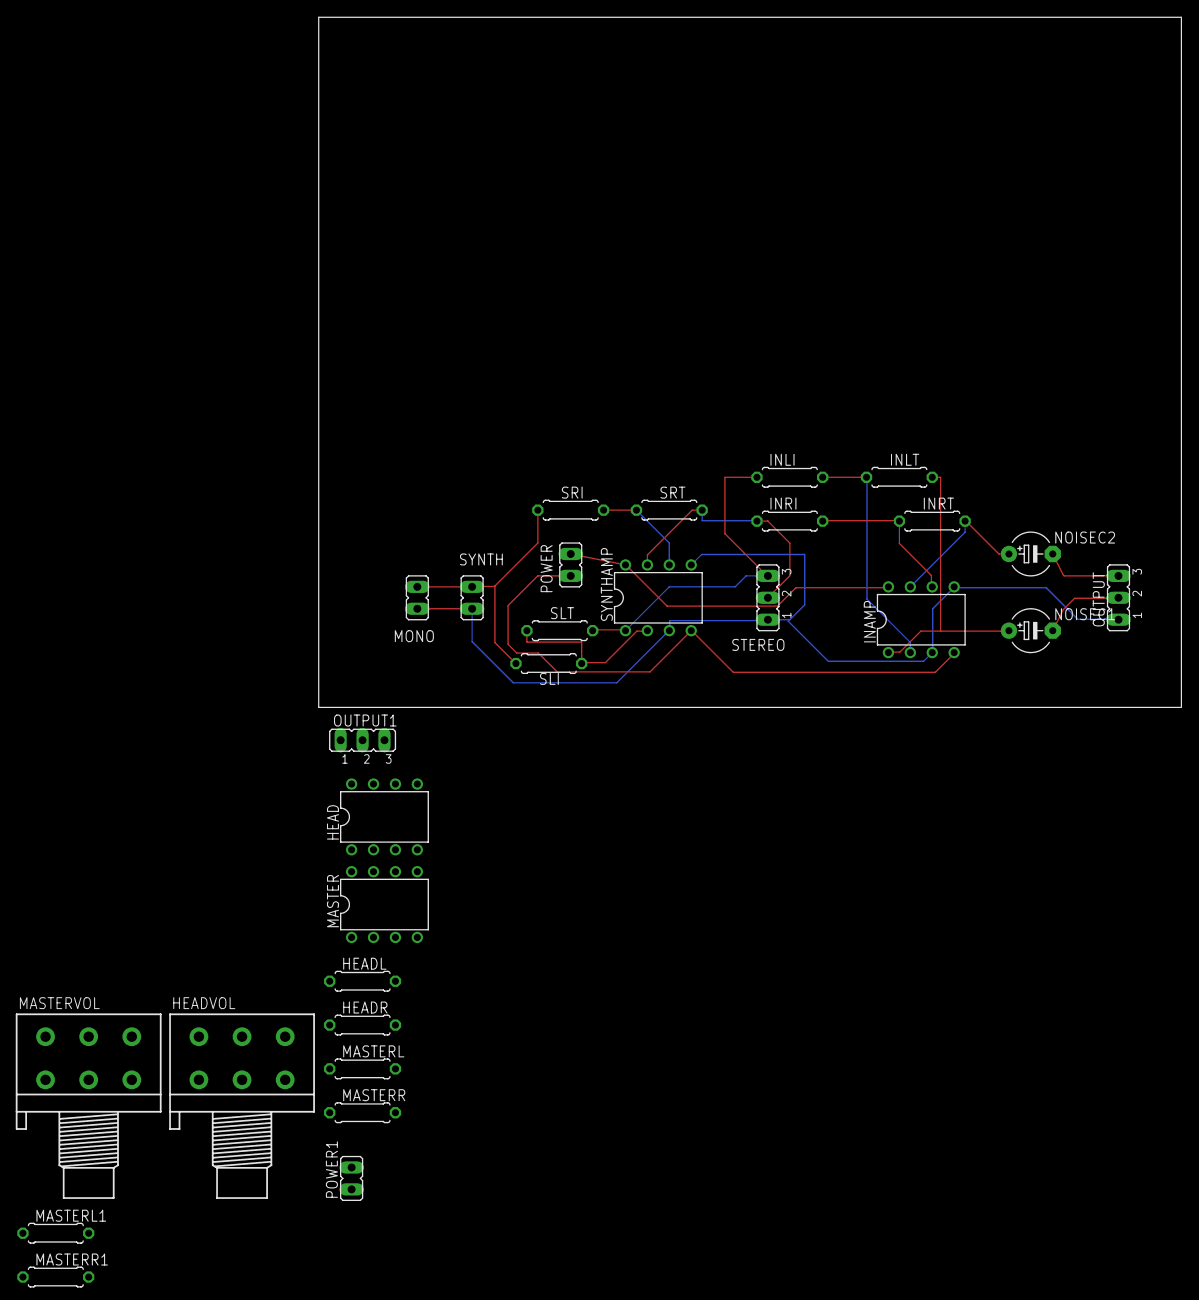
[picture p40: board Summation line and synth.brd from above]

Board: 2 copper layers, 100.0 x 80.0 mm, 29 parts (0 on the bottom side), 24 nets.

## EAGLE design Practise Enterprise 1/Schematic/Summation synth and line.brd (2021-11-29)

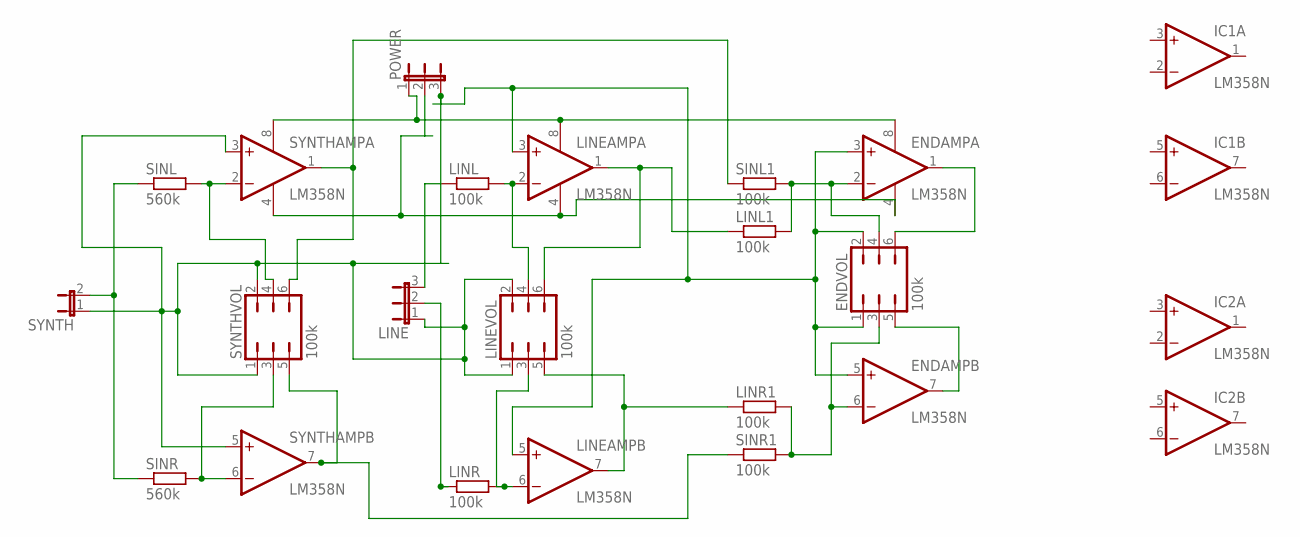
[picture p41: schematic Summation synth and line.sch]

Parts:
ENDAMP: LM358N; DIL08
ENDVOL: 100k; JP3Q
IC1, IC2: LM358N; DIL08
LINE: JP2E; JP2
LINEAMP: LM358N; DIL08
LINEVOL: 100k; JP3Q
LINL, LINL1: 100k; 0207/7
LINR, LINR1: 100k; 0207/7
POWER: JP2E; JP2
SINL: 560k; 0207/7
SINL1: 100k; 0207/7
SINR: 560k; 0207/7
SINR1: 100k; 0207/7
SYNTH: JP1E; JP1
SYNTHAMP: LM358N; DIL08
SYNTHVOL: 100k; JP3Q

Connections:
unnamed: LINE.3, LINL.1
unnamed: SINL.2, SYNTHAMP.2 (-IN), SYNTHVOL.4
unnamed: SINL.1, SINR.1, SYNTH.2
unnamed: LINEAMP.2 (-IN), LINEVOL.4, LINL.2
unnamed: SINR.2, SYNTHAMP.6 (-IN), SYNTHVOL.3
unnamed: SINR1.1, SYNTHAMP.7 (OUT), SYNTHVOL.5
unnamed: LINE.2, LINR.1
unnamed: LINEAMP.6 (-IN), LINEVOL.3, LINR.2
unnamed: LINEAMP.1 (OUT), LINEVOL.6, LINL1.1
unnamed: SINL1.1, SYNTHAMP.1 (OUT), SYNTHVOL.6
unnamed: ENDAMP.6 (-IN), ENDVOL.3, LINR1.2, SINR1.2
unnamed: LINEAMP.7 (OUT), LINEVOL.5, LINR1.1
unnamed: ENDAMP.8 (V+), LINEAMP.8 (V+), POWER.1, SYNTHAMP.8 (V+)
unnamed: ENDAMP.4 (V-), LINEAMP.4 (V-), POWER.2, SYNTHAMP.4 (V-)
unnamed: ENDAMP.3 (+IN), ENDAMP.5 (+IN), ENDVOL.1, ENDVOL.2, LINE.1, LINEAMP.3 (+IN), LINEAMP.5 (+IN), LINEVOL.1, LINEVOL.2, POWER.3, SYNTH.1, SYNTHAMP.3 (+IN), SYNTHAMP.5 (+IN), SYNTHVOL.1, SYNTHVOL.2
unnamed: ENDAMP.2 (-IN), ENDVOL.4, LINL1.2, SINL1.2
unnamed: ENDAMP.1 (OUT), ENDVOL.6
unnamed: ENDAMP.7 (OUT), ENDVOL.5
V+: IC1.8 (V+), IC2.8 (V+)
V-: IC1.4 (V-), IC2.4 (V-)

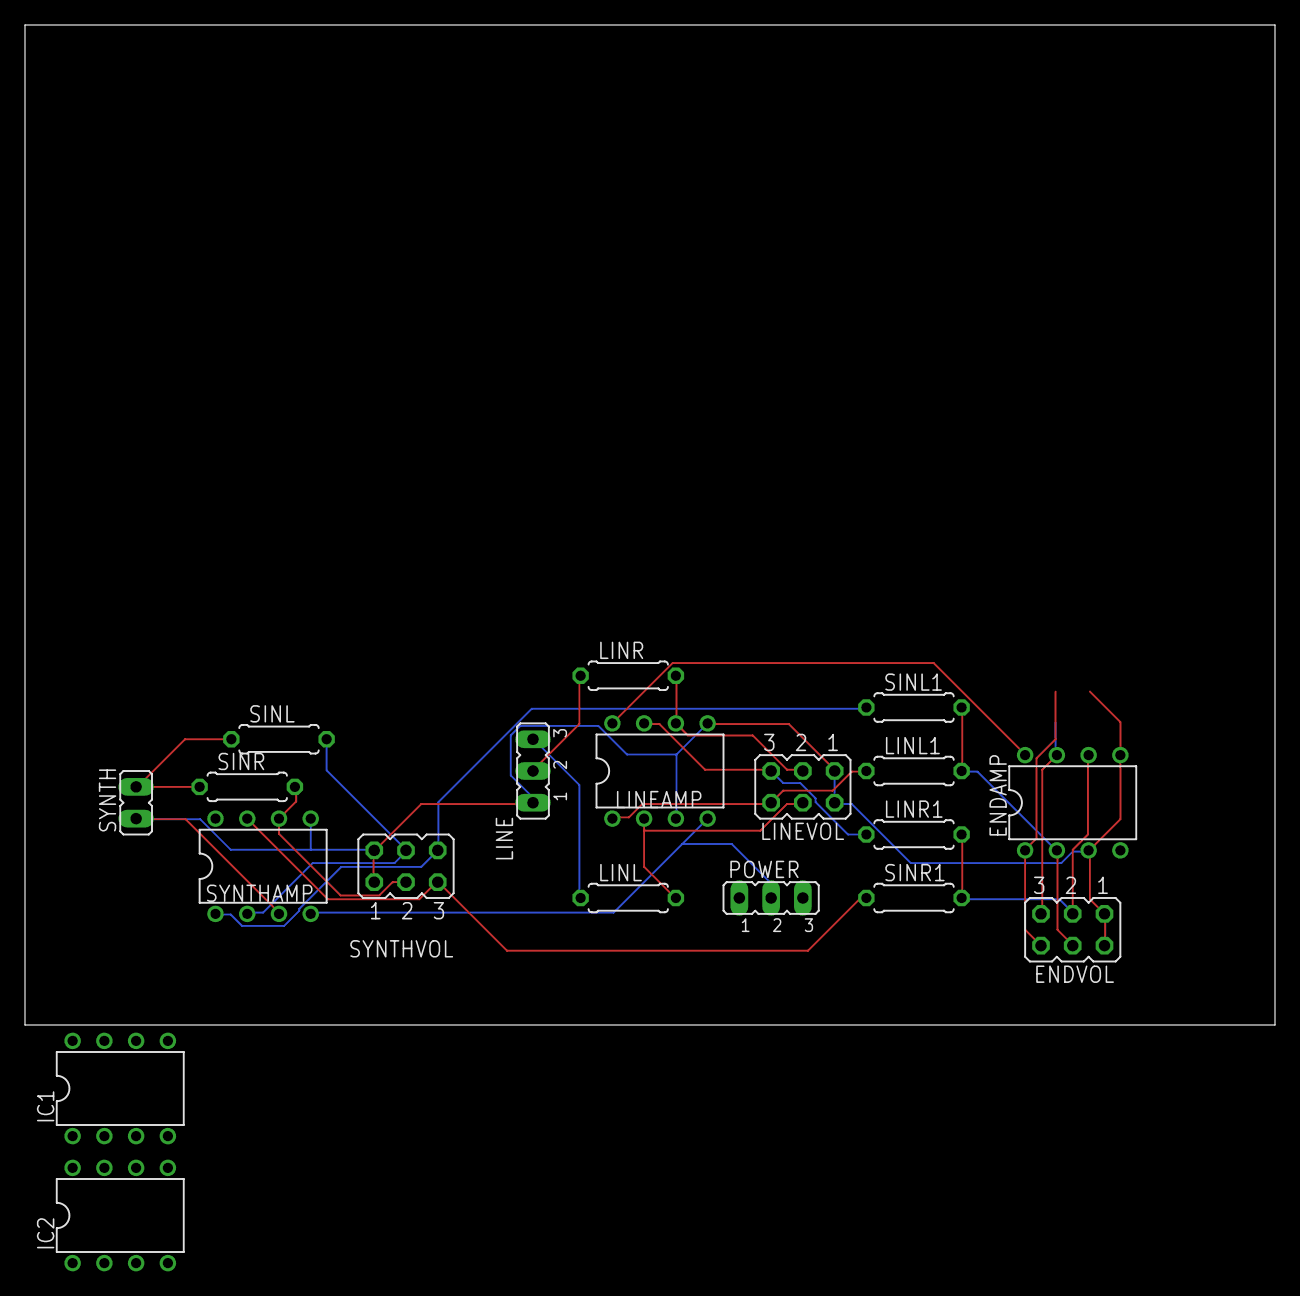
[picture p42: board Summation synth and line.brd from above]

Board: 2 copper layers, 100.0 x 80.0 mm, 19 parts (0 on the bottom side), 20 nets.

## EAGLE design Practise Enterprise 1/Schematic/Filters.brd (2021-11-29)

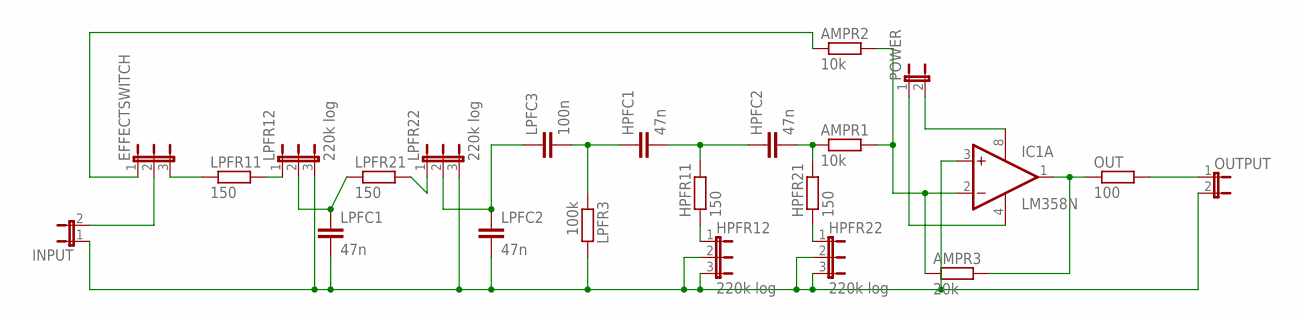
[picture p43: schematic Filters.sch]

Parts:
AMPR1, AMPR2: 10k; 0207/10
AMPR3: 20k; 0207/10
EFFECTSWITCH: 220k log; JP2
HPFC1, HPFC2: 47n; C025-025X050
HPFR11, HPFR21: 150; 0207/10
HPFR12, HPFR22: 220k log; JP2
IC1: LM358N; DIL08
INPUT: JP1E; JP1
LPFC1, LPFC2: 47n; C025-025X050
LPFC3: 100n; C025-025X050
LPFR3: 100k; 0207/10
LPFR11, LPFR21: 150; 0207/10
LPFR12, LPFR22: 220k log; JP2
OUT: 100; 0207/10
OUTPUT: JP1E; JP1
POWER: JP1E; JP1

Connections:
unnamed: LPFR11.2, LPFR12.1
unnamed: LPFC1.1, LPFR12.2, LPFR21.1
unnamed: LPFC2.1, LPFC3.1, LPFR22.2
unnamed: HPFR12.2, HPFR12.3, HPFR22.2, HPFR22.3, IC1.3 (+IN), INPUT.1, LPFC1.2, LPFC2.2, LPFR3.2, LPFR12.3, LPFR22.3, OUTPUT.2
unnamed: EFFECTSWITCH.3, LPFR11.1
unnamed: HPFC1.2, HPFC2.1, HPFR11.2
unnamed: AMPR3.2, IC1.1 (OUT), OUT.1
unnamed: IC1.8 (V+), POWER.2
unnamed: IC1.4 (V-), POWER.1
unnamed: OUT.2, OUTPUT.1
unnamed: AMPR2.1, EFFECTSWITCH.1
unnamed: LPFR21.2, LPFR22.1
unnamed: HPFR21.1, HPFR22.1
unnamed: AMPR1.1, HPFC2.2, HPFR21.2
unnamed: HPFR11.1, HPFR12.1
unnamed: HPFC1.1, LPFC3.2, LPFR3.1
unnamed: EFFECTSWITCH.2, INPUT.2
unnamed: AMPR1.2, AMPR2.2, AMPR3.1, IC1.2 (-IN)

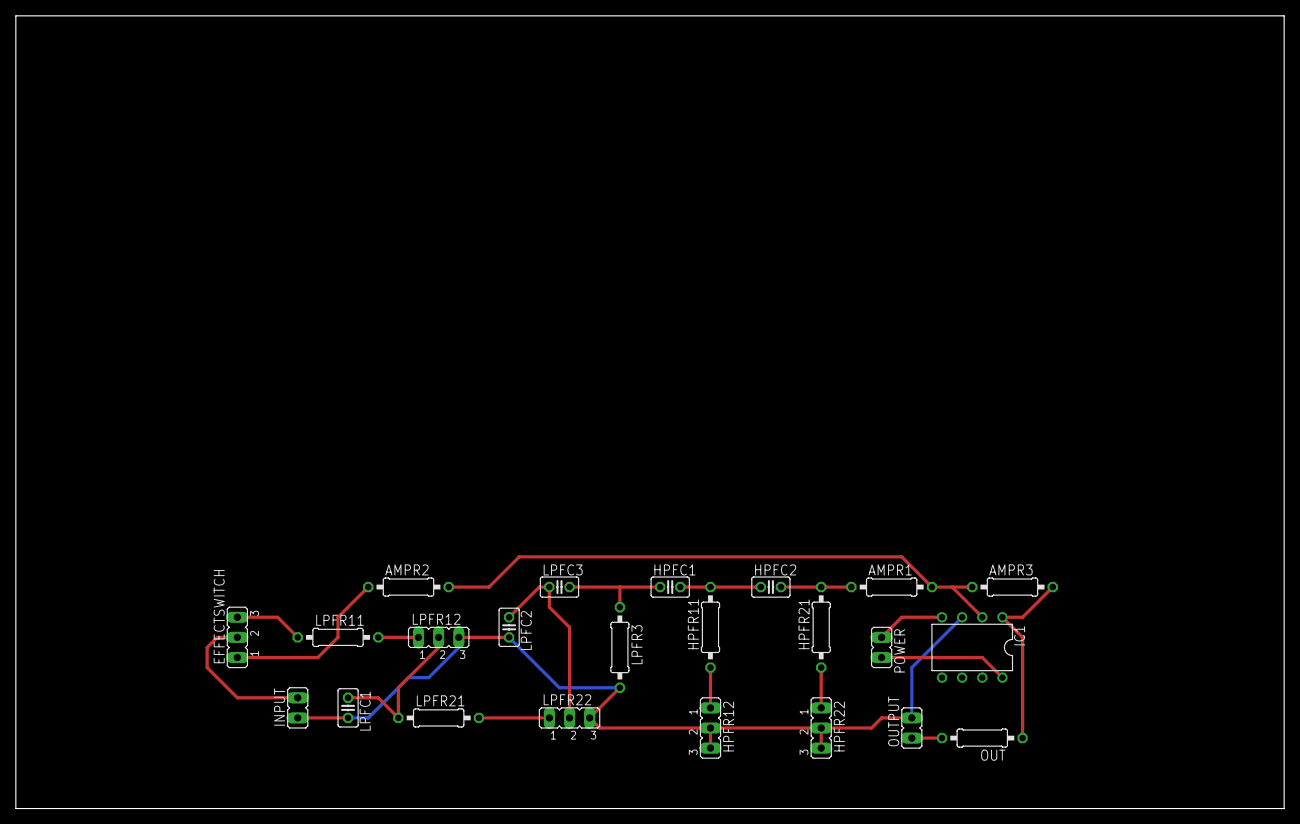
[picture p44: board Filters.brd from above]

Board: 2 copper layers, 160.0 x 100.0 mm, 23 parts (0 on the bottom side), 18 nets.

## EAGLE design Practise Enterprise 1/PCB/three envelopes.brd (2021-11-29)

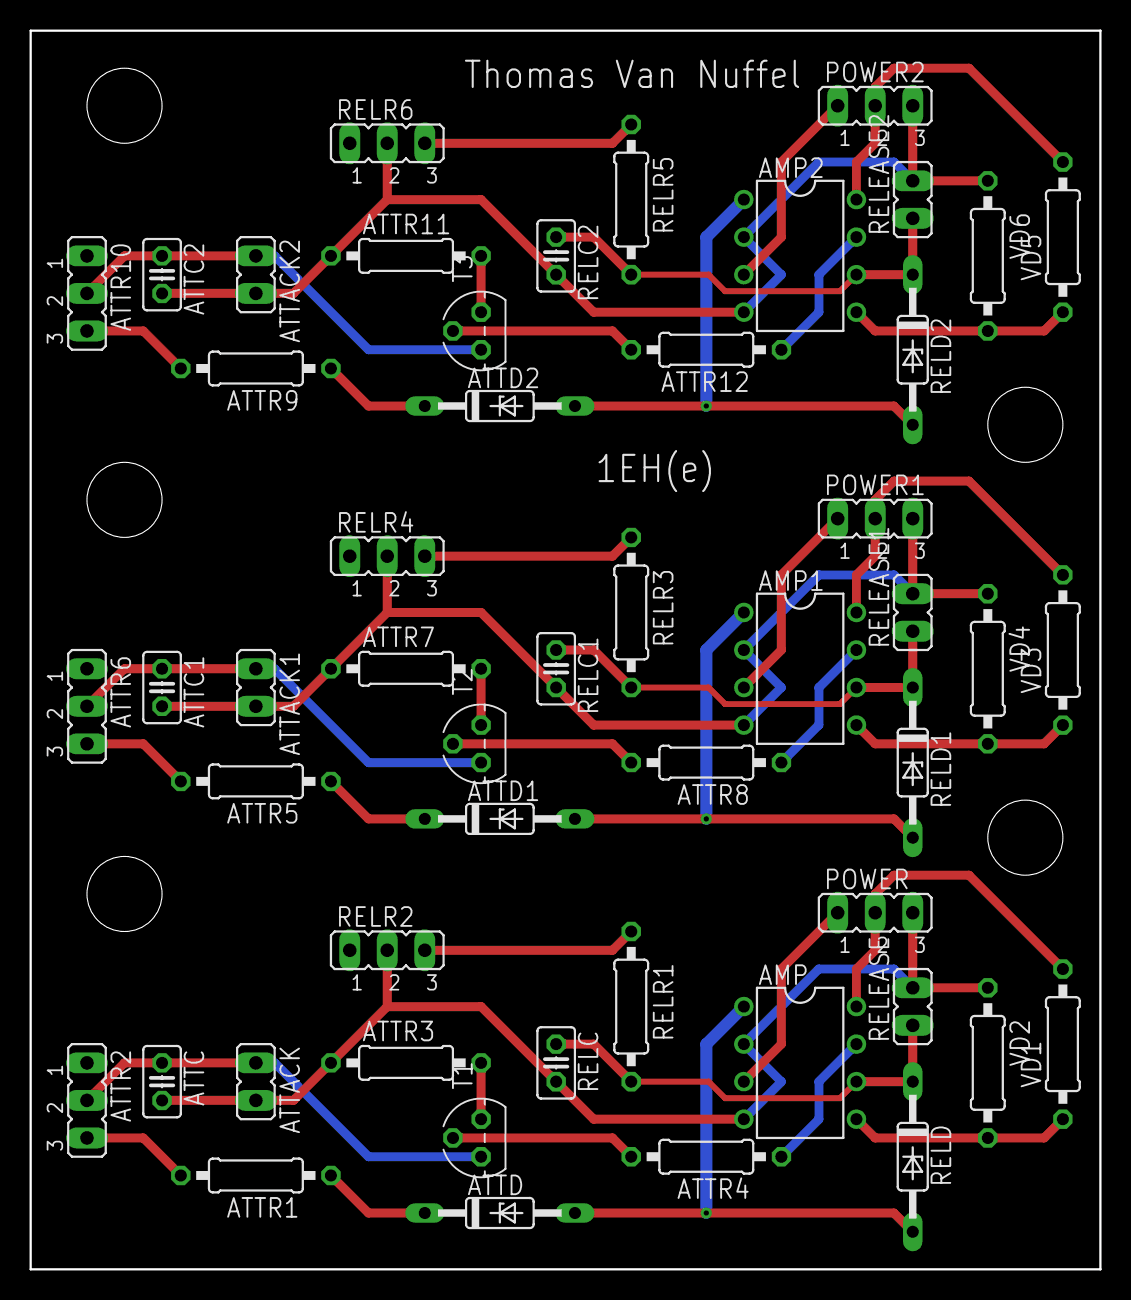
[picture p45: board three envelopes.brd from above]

Board: 2 copper layers, 72.4 x 83.8 mm, 51 parts (0 on the bottom side), 39 nets.

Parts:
AMP, AMP1, AMP2: LM358N; DIL08
ATTACK, ATTACK1, ATTACK2: JP1
ATTC, ATTC1, ATTC2: C025-025X050
ATTD, ATTD1, ATTD2: 1N821; DO35Z10
ATTR1, ATTR3, ATTR4, ATTR5, ATTR7, ATTR8, ATTR9, ATTR11, ATTR12: 0207/10
ATTR2, ATTR6, ATTR10: JP2
POWER, POWER1, POWER2: JP2
RELC, RELC1, RELC2: C025-025X050
RELD, RELD1, RELD2: 1N821; DO35Z10
RELEASE, RELEASE1, RELEASE2: JP1
RELR1, RELR3, RELR5: 0207/10
RELR2, RELR4, RELR6: JP2
T1, T2, T3: BC547; TO92
VD1, VD2, VD3, VD4, VD5, VD6: 0207/10

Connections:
GND: AMP.2, AMP.4, ATTACK.2, ATTC.2, ATTR3.1, POWER.3, RELC.2, RELEASE.2, RELR2.2, VD2.1
GND1: AMP1.2, AMP1.4, ATTACK1.2, ATTC1.2, ATTR7.1, POWER1.3, RELC1.2, RELEASE1.2, RELR4.2, VD4.1
GND2: AMP2.2, AMP2.4, ATTACK2.2, ATTC2.2, ATTR11.1, POWER2.3, RELC2.2, RELEASE2.2, RELR6.2, VD6.1
unnamed: AMP.5, VD1.1, VD2.2
unnamed: AMP.7, ATTR4.1
unnamed: ATTR4.2, T1.2
unnamed: ATTR1.2, ATTR2.3
unnamed: ATTR3.2, T1.1
unnamed: ATTACK.1, ATTC.1, ATTR2.2, T1.3
unnamed: ATTD.C, ATTR1.1
unnamed: AMP.1, ATTD.A, RELD.A
unnamed: AMP.8, POWER.2, VD1.2
unnamed: AMP.3, POWER.1
unnamed: AMP.6, RELC.1, RELD.C, RELEASE.1, RELR1.2
unnamed: RELR1.1, RELR2.3
unnamed: AMP1.5, VD3.1, VD4.2
unnamed: AMP1.7, ATTR8.1
unnamed: ATTR8.2, T2.2
unnamed: ATTR7.2, T2.1
unnamed: ATTACK1.1, ATTC1.1, ATTR6.2, T2.3
unnamed: ATTD1.C, ATTR5.1
unnamed: ATTR5.2, ATTR6.3
unnamed: AMP1.1, ATTD1.A, RELD1.A
unnamed: AMP1.8, POWER1.2, VD3.2
unnamed: AMP1.6, RELC1.1, RELD1.C, RELEASE1.1, RELR3.2
unnamed: AMP1.3, POWER1.1
unnamed: RELR3.1, RELR4.3
unnamed: AMP2.5, VD5.1, VD6.2
unnamed: AMP2.7, ATTR12.1
unnamed: ATTR12.2, T3.2
unnamed: ATTR11.2, T3.1
unnamed: ATTACK2.1, ATTC2.1, ATTR10.2, T3.3
unnamed: ATTD2.C, ATTR9.1
unnamed: ATTR9.2, ATTR10.3
unnamed: AMP2.1, ATTD2.A, RELD2.A
unnamed: AMP2.8, POWER2.2, VD5.2
unnamed: AMP2.6, RELC2.1, RELD2.C, RELEASE2.1, RELR5.2
unnamed: AMP2.3, POWER2.1
unnamed: RELR5.1, RELR6.3

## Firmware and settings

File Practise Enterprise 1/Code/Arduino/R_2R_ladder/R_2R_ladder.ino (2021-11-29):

#define timer 1
#define pins 2

void setup()
{
  pinMode(2, OUTPUT);
  pinMode(3, OUTPUT);
  pinMode(4, OUTPUT);
  pinMode(5, OUTPUT);
  pinMode(6, OUTPUT);
  pinMode(7, OUTPUT);
  pinMode(8, OUTPUT);
  pinMode(9, OUTPUT);
}

void loop()
{
  int count = 0;
  count = pins * pins;
  digitalWrite(2,HIGH);
  delay((float)timer/count);
  digitalWrite(2,LOW);
  digitalWrite(3,HIGH);
  delay((float)timer/count);
  digitalWrite(2,HIGH);
  delay((float)timer/count);
  digitalWrite(2,LOW);
  digitalWrite(3,LOW);
  digitalWrite(4,HIGH);
  delay((float)timer/count);
  digitalWrite(2,HIGH);
  delay((float)timer/count);
  digitalWrite(2,LOW);
  digitalWrite(3,HIGH);
  delay((float)timer/count);
  digitalWrite(2,HIGH);
  delay((float)timer/count);
  digitalWrite(2,LOW);
  digitalWrite(3,LOW);
  digitalWrite(4,LOW);
  digitalWrite(5,HIGH);
  delay((float)timer/count);
  digitalWrite(2,HIGH);
  delay((float)timer/count);
  digitalWrite(2,LOW);
  digitalWrite(3,HIGH);
  delay((float)timer/count);
  digitalWrite(2,HIGH);
  delay((float)timer/count);
  digitalWrite(2,LOW);
  digitalWrite(3,LOW);
  digitalWrite(4,HIGH);
  delay((float)timer/count);
  digitalWrite(2,HIGH);
  delay((float)timer/count);
  digitalWrite(2,LOW);
  digitalWrite(3,HIGH);
  delay((float)timer/count);
  digitalWrite(2,HIGH);
  delay((float)timer/count);
  digitalWrite(2,LOW);
  digitalWrite(3,LOW);
  digitalWrite(4,LOW);
  digitalWrite(5,LOW);
  delay((float)timer/count);
}
